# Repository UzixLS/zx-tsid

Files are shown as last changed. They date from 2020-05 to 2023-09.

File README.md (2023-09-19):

## ZX-TSid
MOS SID sound card for ZX Spectrum edge connector (ZX-BUS).

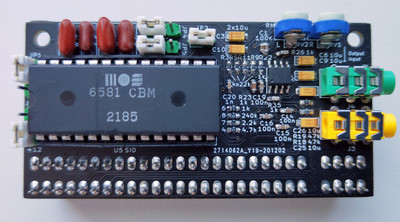
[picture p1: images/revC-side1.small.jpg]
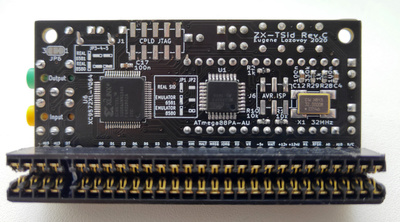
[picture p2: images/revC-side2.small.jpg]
 

PCB is compatible with SID 6581 and 8580, but also contains integrated SwinSID emulator.

SID accessible via #xxCF port, where xx - SID's register number.

You may connect your ZX Spectrum audio output to second 3.5mm jack and it will be mixed in sound card output signal.

NOTE: +12V/+9V voltage is strictly required for SID, your ZX Spectrum or clone must provide it on the edge connector.

### Changelog & current status
* Rev.A - initial release with SID, AY and Covox. [Errata](pcb/rev.A/ERRATA.txt).
* Rev.B - abandoned. Files kept for historical reason.
* Rev.C - removed AY and Covox. Added SwinSID emulator. PCB is vertical oriented now.
* Rev.D - improved signal-noise ratio. Fixed read from SID chip.

TODO:
* Check with 8580 SID chip;
* Further improve signal-noise ratio.

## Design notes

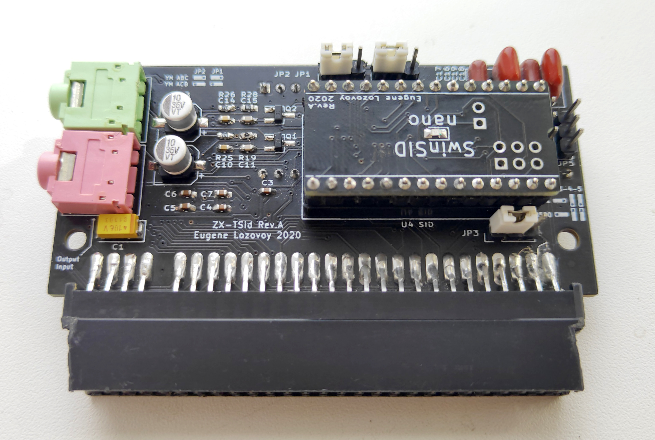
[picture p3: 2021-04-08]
images/revA-side1.jpg

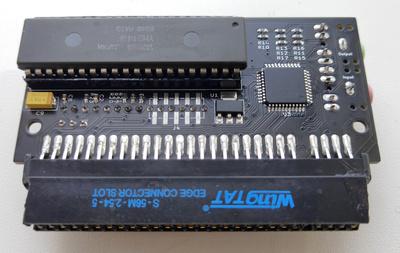
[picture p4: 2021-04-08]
images/revA-side2.small.jpg

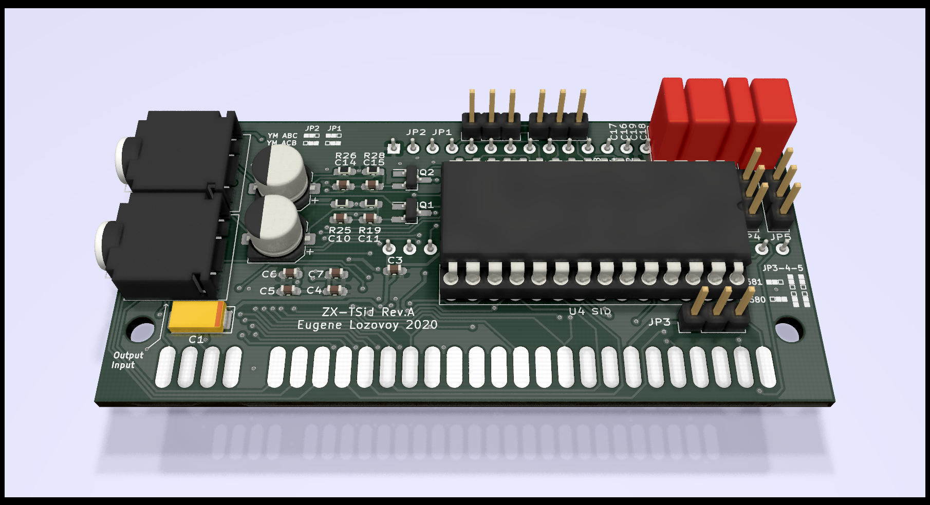
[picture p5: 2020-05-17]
out/pcb3d-top.rev.A.png

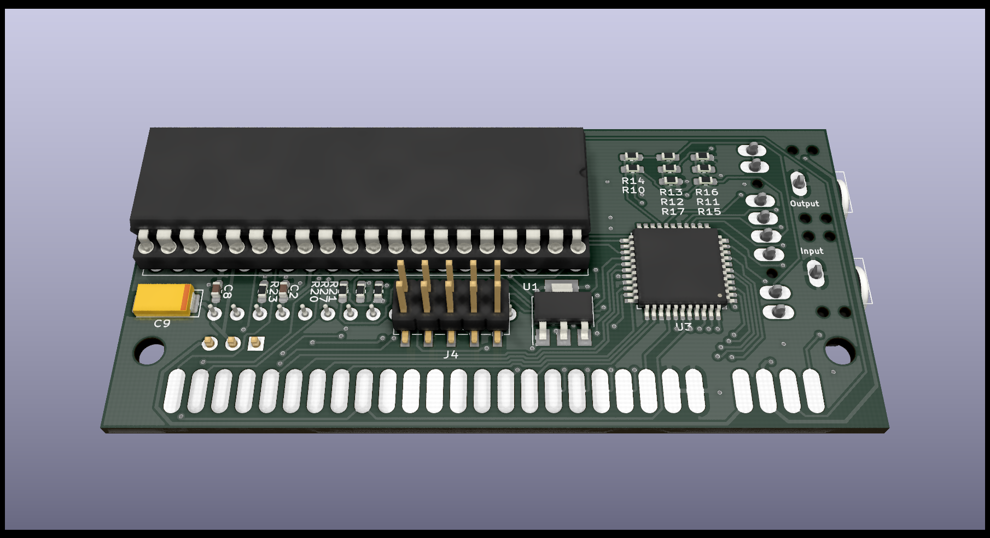
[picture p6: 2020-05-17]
out/pcb3d-bottom.rev.A.png

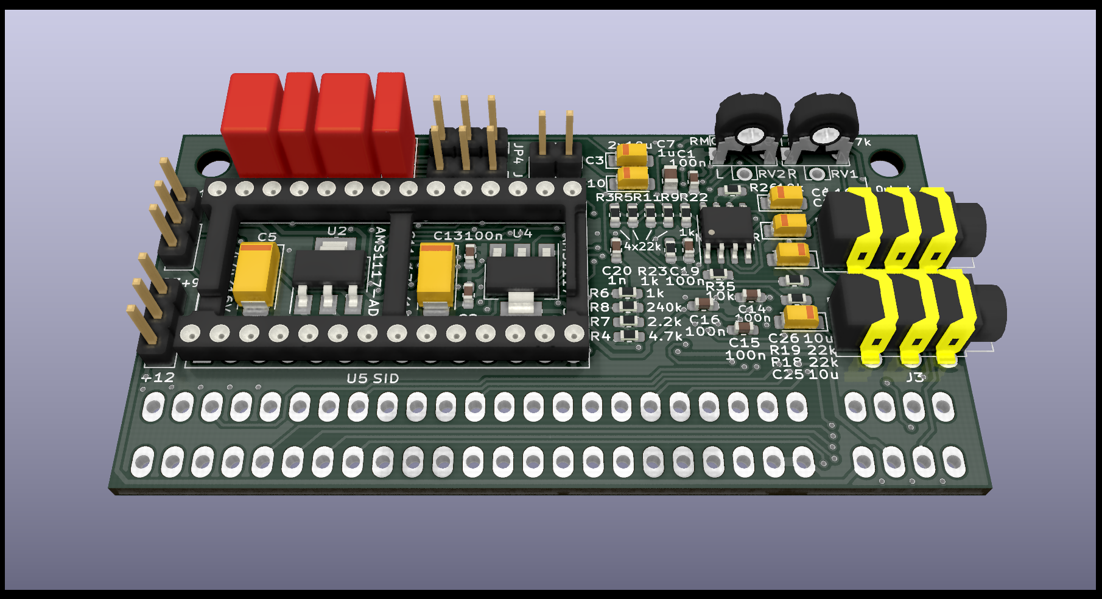
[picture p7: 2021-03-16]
out/pcb3d-bottom.rev.D.png

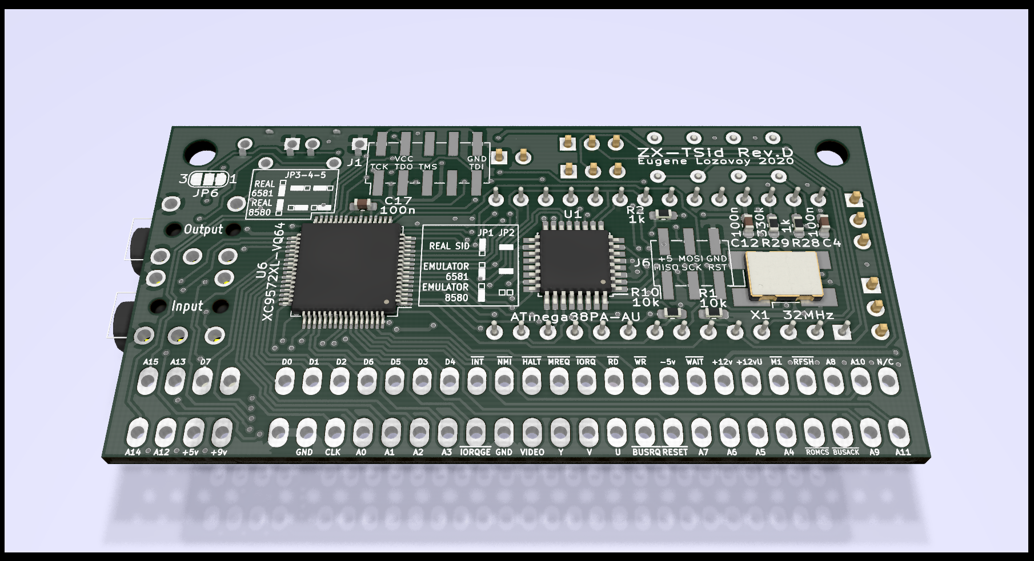
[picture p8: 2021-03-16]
out/pcb3d-top.rev.D.png

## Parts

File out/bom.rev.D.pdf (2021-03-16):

Designator | Package | Designation | Quantity
C11,C5 | CP_EIA-6032-28_Kemet-C_Pad2.25x2.35mm_HandSolder | 47u/16V | 2
C2,C19,C1,C4,C12,C17,C1 6,C15,C14,C13 | C_0603_1608Metric_Pad1.05x0.95mm_HandSolder | 100n | 10
C20 | C_0603_1608Metric_Pad1.05x0.95mm_HandSolder | 1n | 1
C22,C18 | C_Rect_L7.0mm_W4.5mm_P5.00mm | 470p | 2
C24,C21 | C_Rect_L7.0mm_W2.5mm_P5.00mm | 22n | 2
C3,C26,C25,C10,C6,C9 | CP_EIA-3216-18_Kemet-A_Pad1.58x1.35mm_HandSolder | 10u | 6
C7 | C_0805_2012Metric_Pad1.15x1.40mm_HandSolder | 1u | 1
H2,H1 | MountingHole_3.2mm_M3 | MountingHole | 2
J1 | PinHeader_2x05_P2.54mm_Vertical_SMD | Conn_02x05_Odd_Even | 1
J4,J3 | PJ-313 | PJ-313 | 2
J6 | PinHeader_2x03_P2.54mm_Vertical_SMD | Conn_02x03_Odd_Even | 1
JP1,JP5,JP4,JP3 | PinHeader_1x03_P2.54mm_Vertical | Jumper_3_Open | 4
JP2 | PinHeader_1x02_P2.54mm_Vertical | Jumper | 1
R10,R1,R35,R26 | R_0603_1608Metric_Pad1.05x0.95mm_HandSolder | 10k | 4
R11,R3,R9,R5,R19,R18 | R_0603_1608Metric_Pad1.05x0.95mm_HandSolder | 22k | 6
R12 | R_0603_1608Metric_Pad1.05x0.95mm_HandSolder | 240 | 1
R13,R6,R2,R23,R22,R28 | R_0603_1608Metric_Pad1.05x0.95mm_HandSolder | 1k | 6
R29 | R_0603_1608Metric_Pad1.05x0.95mm_HandSolder | 330k | 1
R4 | R_0603_1608Metric_Pad1.05x0.95mm_HandSolder | 4.7k | 1
R7 | R_0603_1608Metric_Pad1.05x0.95mm_HandSolder | 2.2k | 1
R8 | R_0603_1608Metric_Pad1.05x0.95mm_HandSolder | 240k | 1
RV2,RV1 | Potentiometer_Runtron_RM-063_Horizontal | RM063 47k | 2
U1 | TQFP-32_7x7mm_P0.8mm | ATmega88PA-AU | 1
U2 | SOT-223-3_TabPin2 | AMS1117-ADJ | 1
U3 | SOIC-8_3.9x4.9mm_P1.27mm | NE5532DR | 1
U4 | SOT-223-3_TabPin2 | AMS1117-3.3 | 1
U5 | DIP-28_W15.24mm_Socket | 8580 | 1
U6 | TQFP-64_10x10mm_P0.5mm | XC9572XL-VQ64 | 1
X1 | Oscillator_SMD_EuroQuartz_XO91-4Pin_7.0x5.0mm_HandSoldering | 32MHz | 1

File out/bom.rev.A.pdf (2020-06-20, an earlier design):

Designator | Package | Designation | Quantity
C10,C14 | C_0603_1608Metric_Pad1.05x0.95mm_HandSolder | 1n | 2
C11,C15 | C_0603_1608Metric_Pad1.05x0.95mm_HandSolder | 470p | 2
C12,C13 | CP_Elec_6.3x5.4 | 10u | 2
C18,C16 | C_Rect_L7.0mm_W4.5mm_P5.00mm | 470p | 2
C19,C17 | C_Rect_L7.0mm_W2.5mm_P5.00mm | 22n | 2
C8,C2,C7,C6,C5,C4,C3 | C_0603_1608Metric_Pad1.05x0.95mm_HandSolder | 100n | 7
C9,C1 | CP_EIA-6032-15_Kemet-U_Pad2.25x2.35mm_HandSolder | 100u/16V | 2
H2,H1 | MountingHole_3.2mm_M3 | MountingHole | 2
J1 | ZX_CONN | zx_edge | 1
J2,J3 | SWITCHCRAFT_35RAPC4BHN2 | PJ307 | 2
J4 | PinHeader_2x05_P2.54mm_Vertical_SMD | Conn_02x05_Odd_Even | 1
JP5,JP4,JP3,JP2,JP1 | PinHeader_1x03_P2.54mm_Vertical | Jumper_3_Open | 5
Q1,Q2 | SOT-23_Handsoldering | BC847 | 2
R17,R16,R15,R10,R13,R12,R11,R 14,R6,R2,R27,R21,R20 | R_0603_1608Metric_Pad1.05x0.95mm_HandSolder | 10k | 13
R19,R9,R8,R7,R1,R28,R22 | R_0603_1608Metric_Pad1.05x0.95mm_HandSolder | 1k | 7
R23 | R_0603_1608Metric_Pad1.05x0.95mm_HandSolder | 100k | 1
R24,R18 | R_0603_1608Metric_Pad1.05x0.95mm_HandSolder | 22k | 2
R26,R25 | R_0603_1608Metric_Pad1.05x0.95mm_HandSolder | 47k | 2
R4 | R_0603_1608Metric_Pad1.05x0.95mm_HandSolder | 4.7k | 1
R5,R3 | R_0603_1608Metric_Pad1.05x0.95mm_HandSolder | 2k | 2
U1 | SOT-223-3_TabPin2 | AMS1117-3.3 | 1
U2 | DIP-40_W15.24mm_Socket | YM2149 | 1
U3 | QFP80P1200X1200X120-44N | EPM3064ATC44-10N | 1
U4 | DIP-28_W15.24mm_Socket | 8580 | 1

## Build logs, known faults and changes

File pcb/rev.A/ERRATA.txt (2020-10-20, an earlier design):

Quiet sound output from nanoSwinSID.

Incorrect A8 and A10 signal connections on ZXBUS connector. A8 should be connected to pin B26 and A10 to B27 to get SID working.

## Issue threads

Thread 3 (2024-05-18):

ask for add ZXi ports

LMN128, 2024-05-18:
Could you add access by ZXi ports too, please. Some SW use it. It comes better compatibility. Thanks a lot.
Info here: https://sinclair.wiki.zxnet.co.uk/wiki/ZXI_standard

tech spec:
```
ZX Spectrum SID on ZXi ports

h6C3B – select SID Control Register
h6D3B – read/write selected SID Control Register

Registers:
h00 to h1C - original SID registers

h1F - optional - select SID parameters
	bit 0 - SID type:  0-6581; 1-8580
	bit 1 - Frequency: 0-PAL;  1-NTSC (985248Hz for PAL C64, 1022730Hz for NTSC C64)
	bits 2-7 - always 0;
	note eLeMeNt ZX and MB03+ use FPGA implementation of SID that can switch type with related filters.

h20 - optional - select more SIDs (up to 256 SIDs) - useful for more than one SID
	       - in case of only one SID, is not needed to use it.

```

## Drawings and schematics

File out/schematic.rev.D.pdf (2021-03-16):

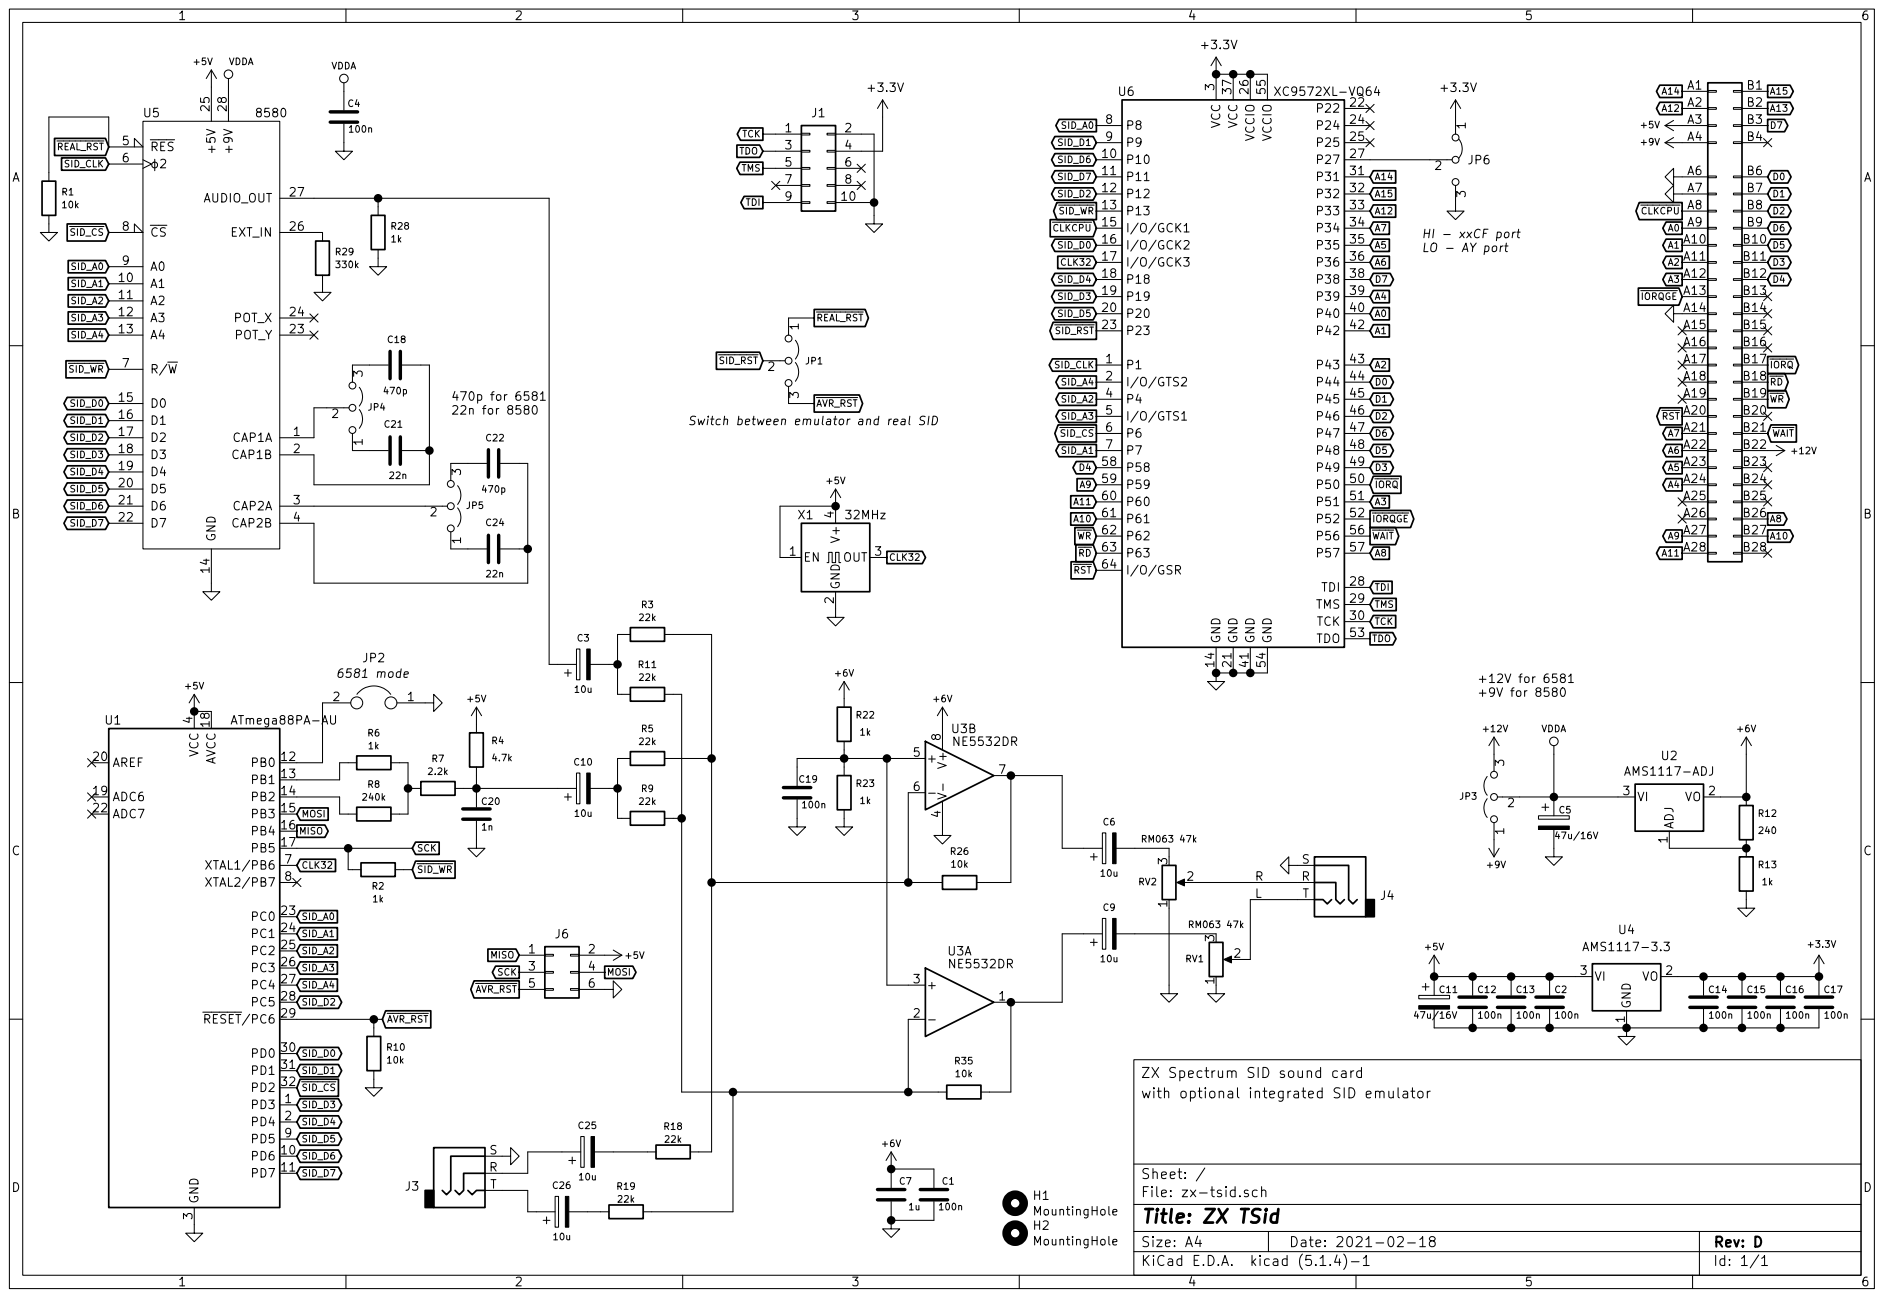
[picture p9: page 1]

LO - AY port +12V for 6581 +9V for 8580

JP1 Switch between emulator and real SID

ZX Spectrum SID sound card
File: zx-tsid.sch Sheet: / with optional integrated SID emulator

Id: 1/1 Title: ZX TSid

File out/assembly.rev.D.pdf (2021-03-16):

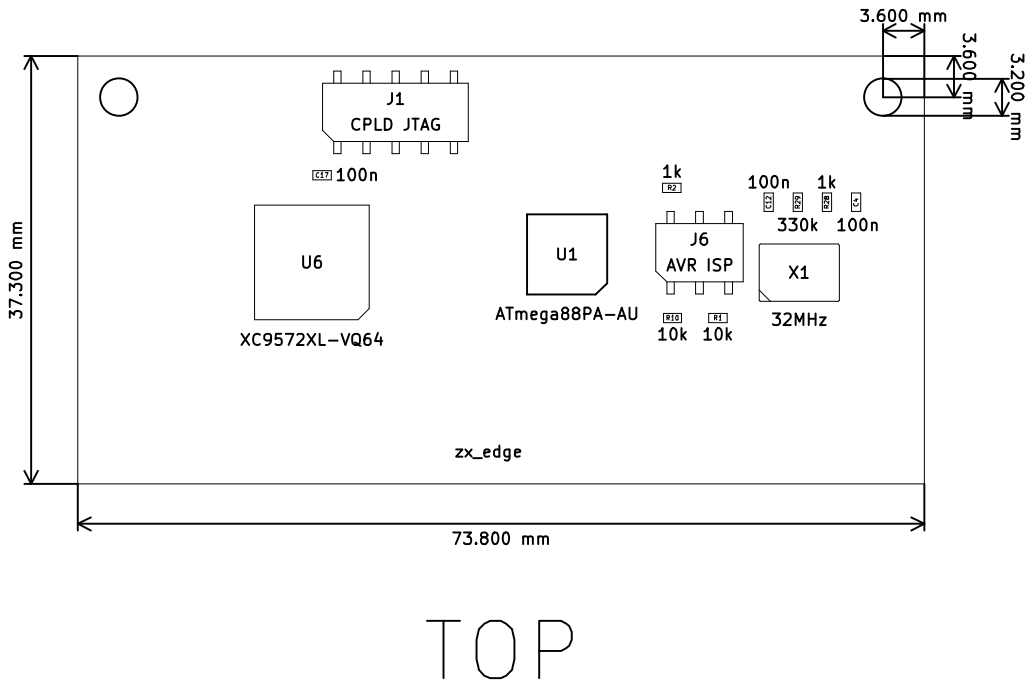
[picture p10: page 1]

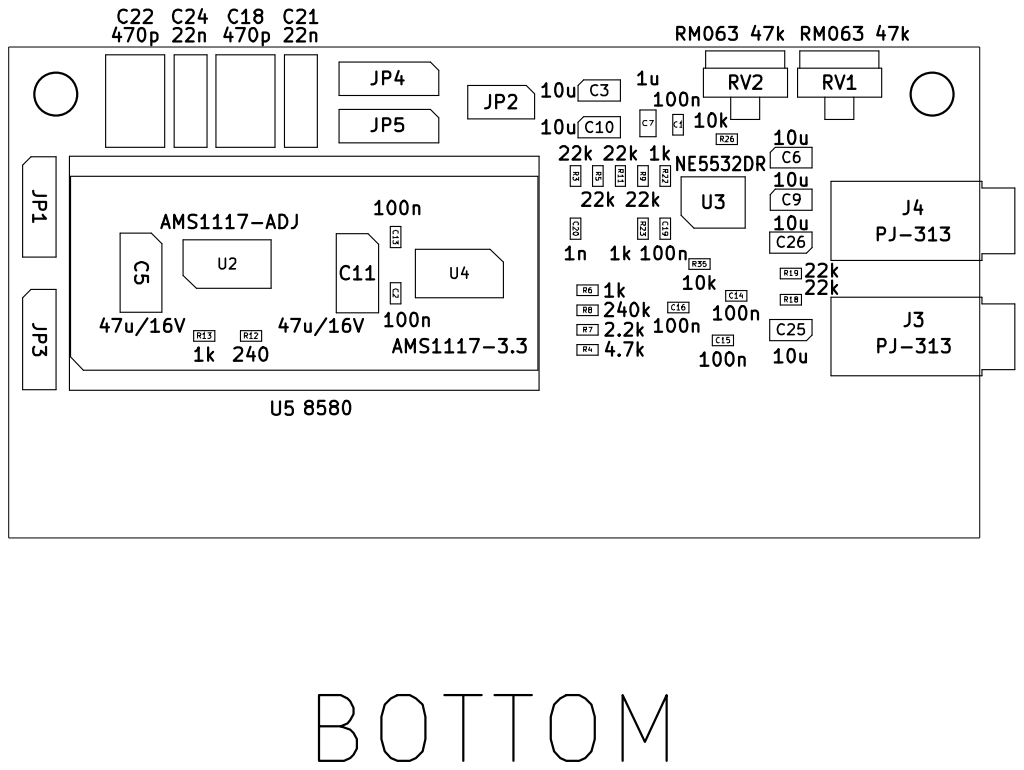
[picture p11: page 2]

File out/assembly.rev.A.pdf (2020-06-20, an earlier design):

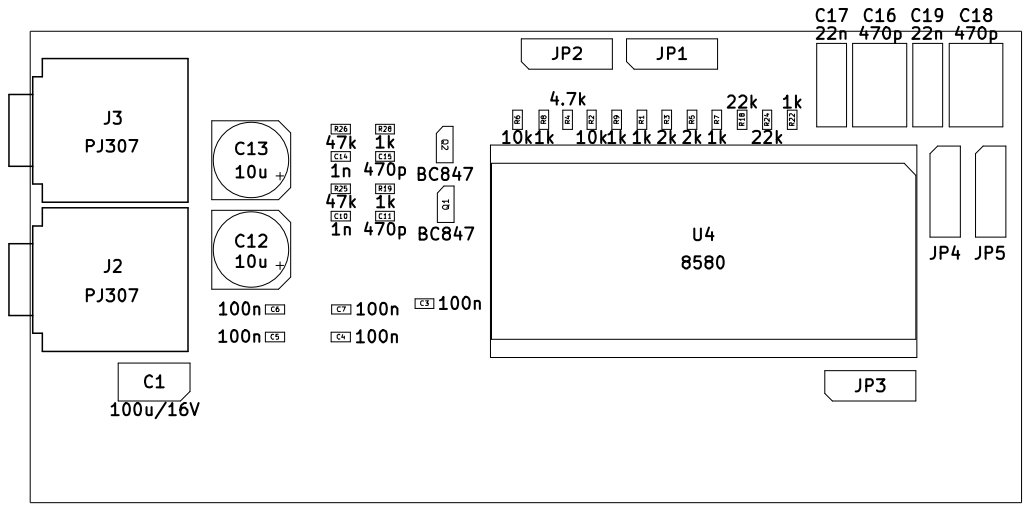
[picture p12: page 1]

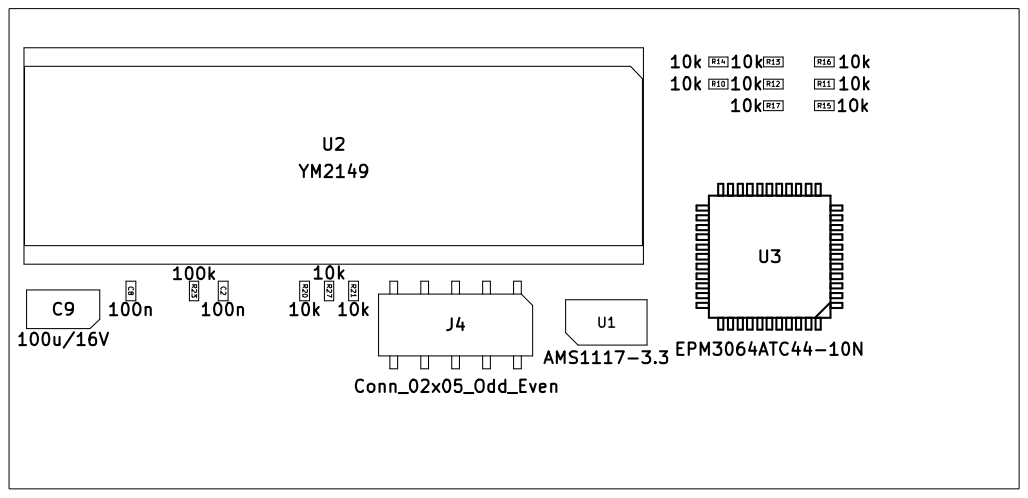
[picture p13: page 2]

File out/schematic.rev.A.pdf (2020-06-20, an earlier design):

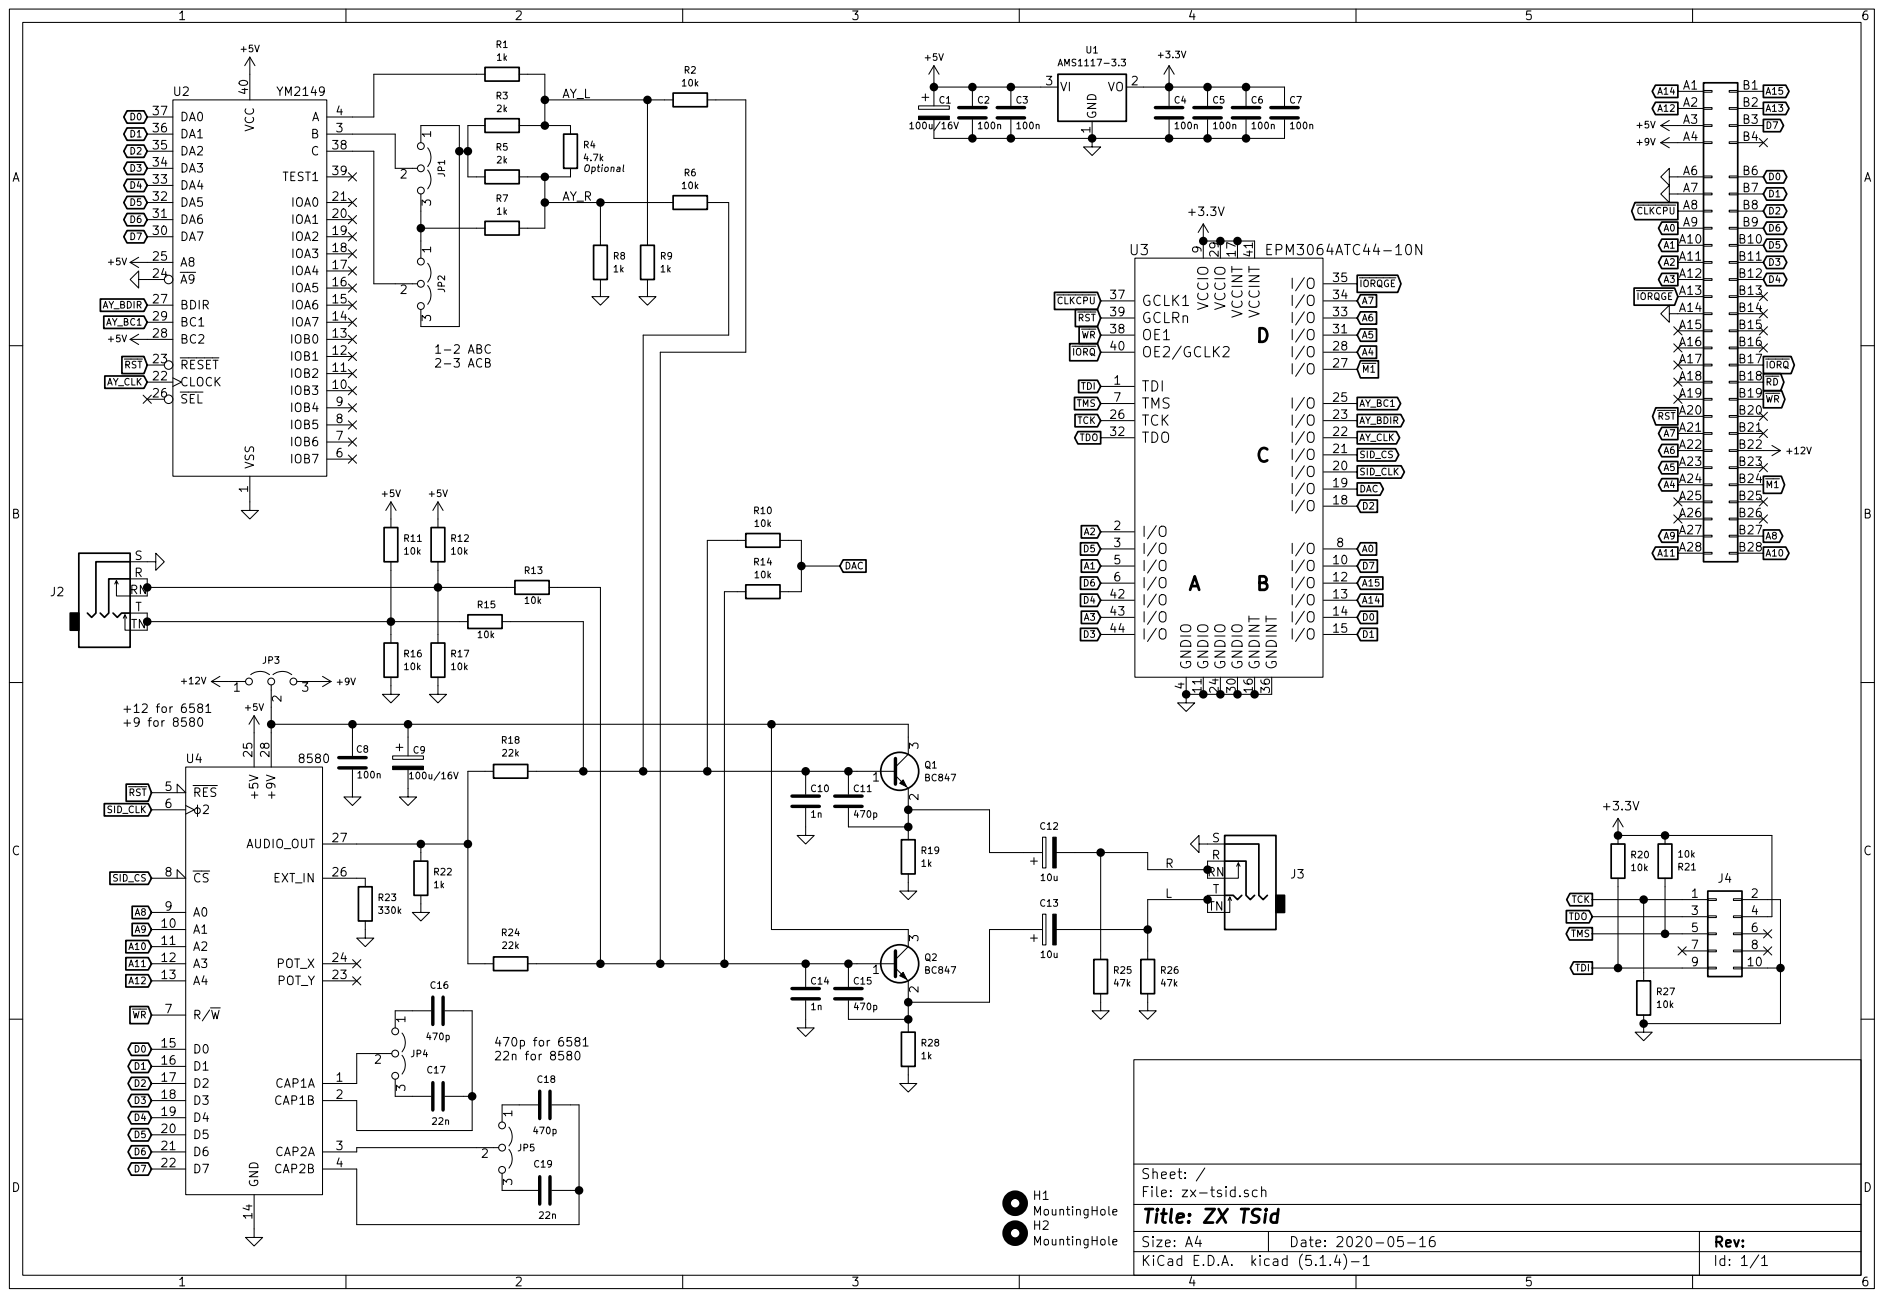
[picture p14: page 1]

File: zx-tsid.sch Sheet: /
Id: 1/1 Title: ZX TSid

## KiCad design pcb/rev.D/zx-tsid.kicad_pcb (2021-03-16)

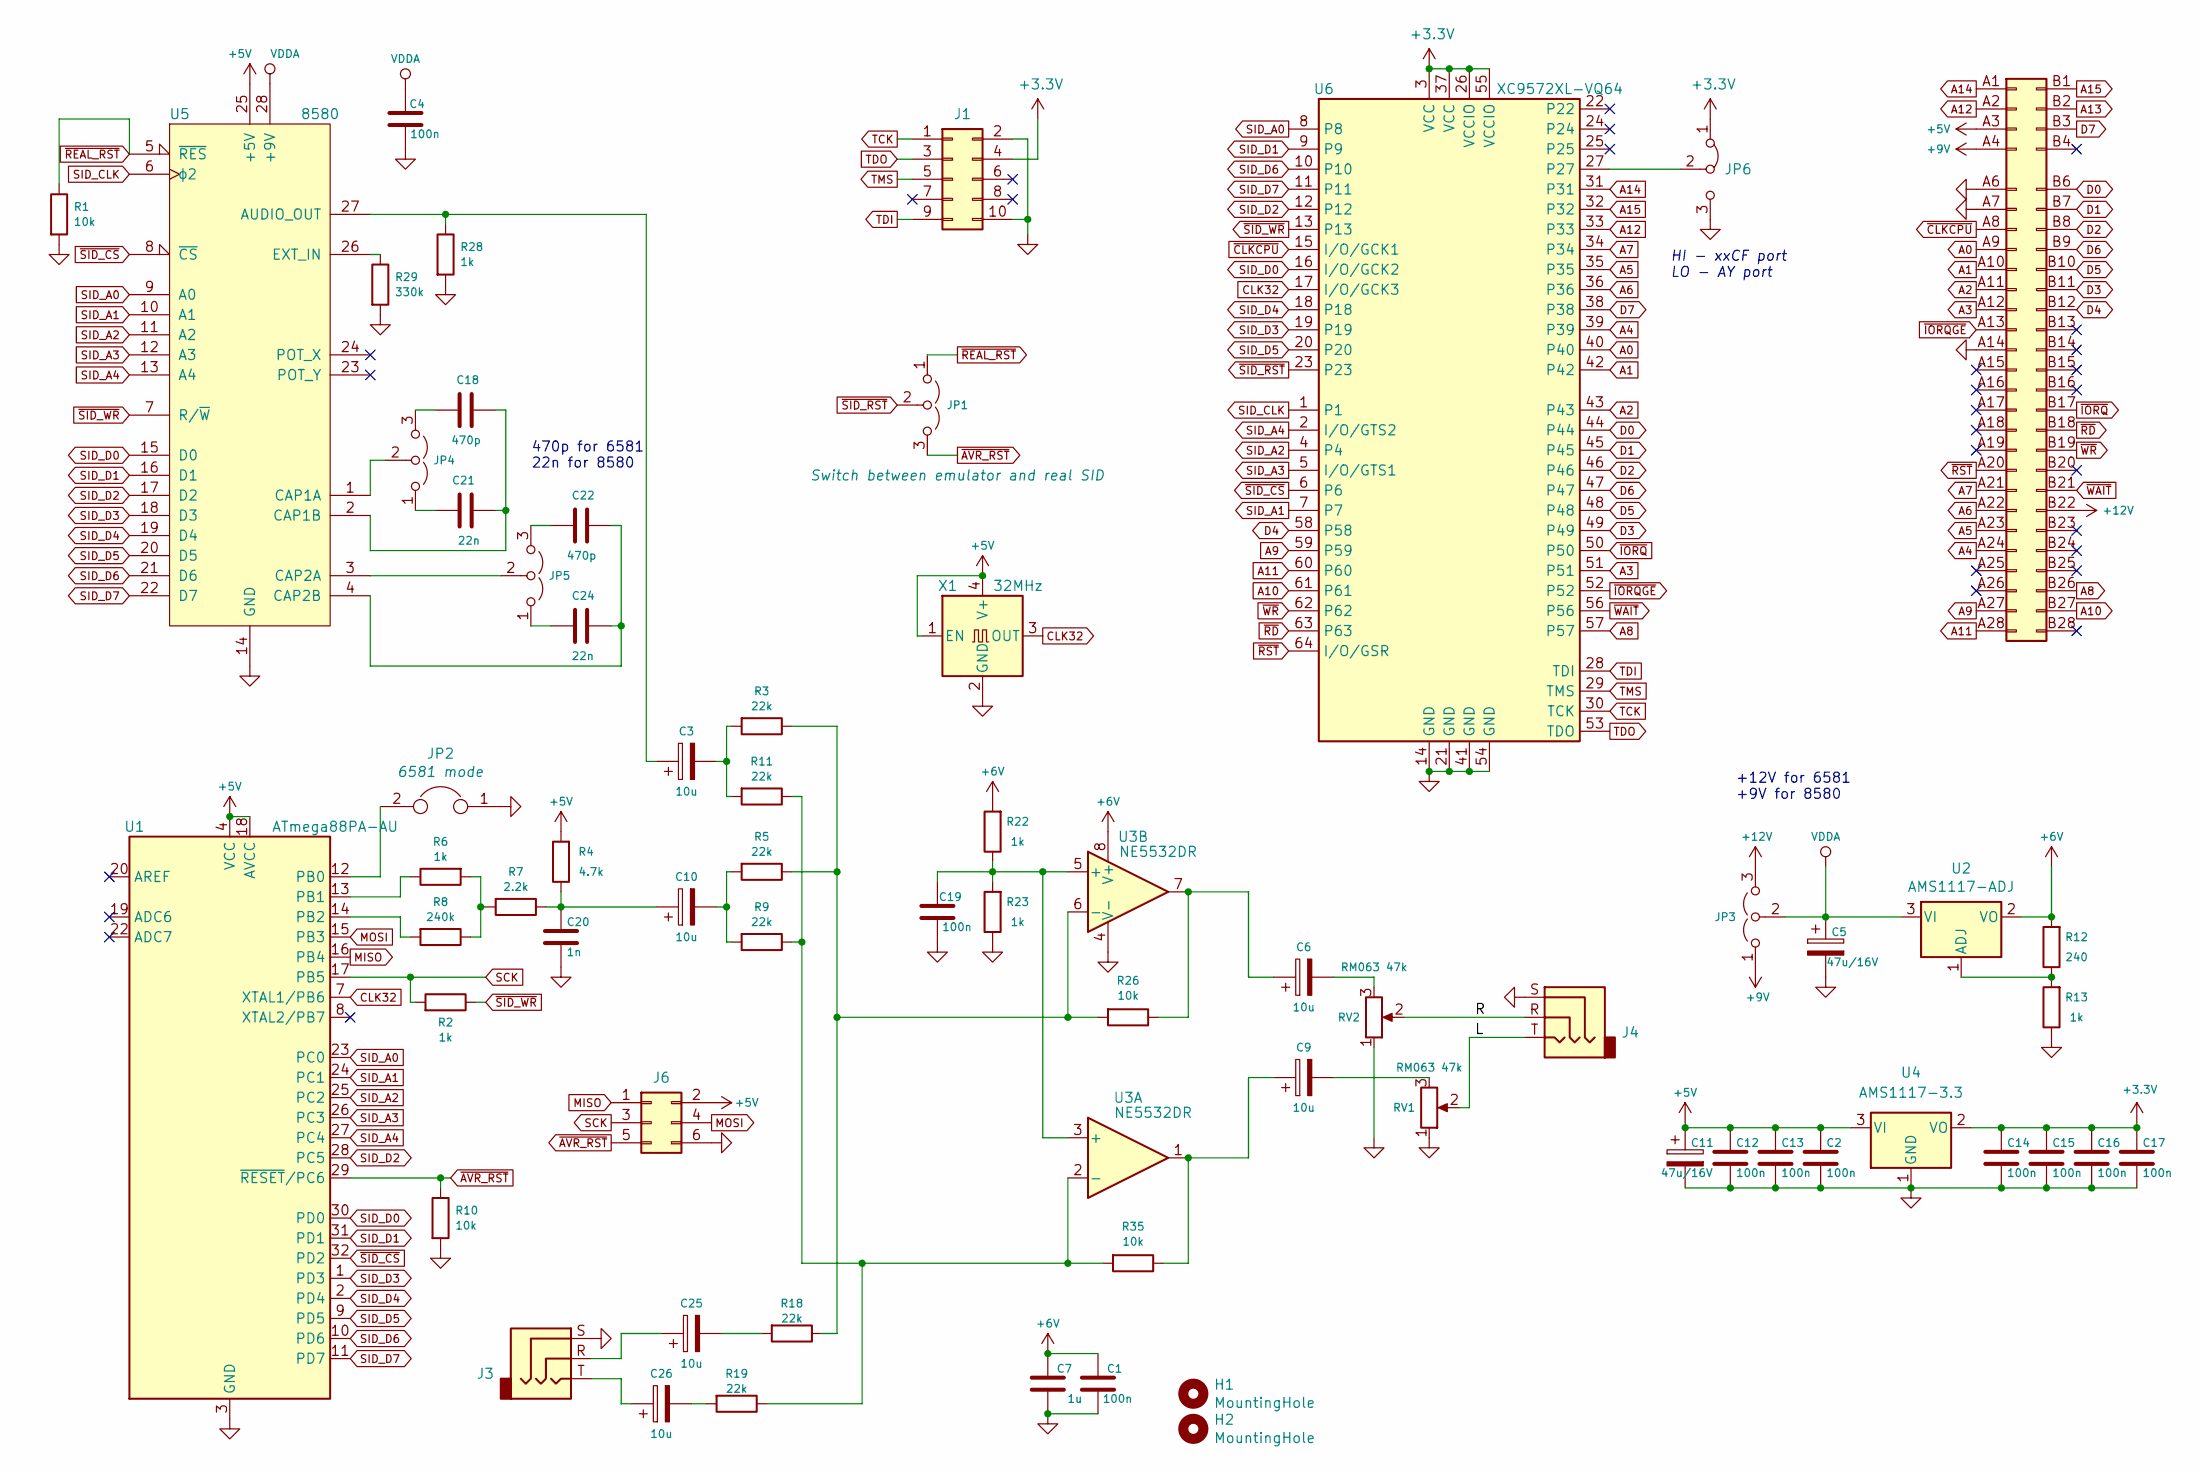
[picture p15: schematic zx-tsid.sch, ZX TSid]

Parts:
C1, C2, C4, C12, C13, C14, C15, C16, C17, C19: 100n; C_0603_1608Metric_Pad1.05x0.95mm_HandSolder
C3, C6, C9, C10, C25, C26: 10u; CP_EIA-3216-18_Kemet-A_Pad1.58x1.35mm_HandSolder
C5, C11: 47u/16V; CP_EIA-6032-28_Kemet-C_Pad2.25x2.35mm_HandSolder
C7: 1u; C_0805_2012Metric_Pad1.15x1.40mm_HandSolder
C18, C22: 470p; C_Rect_L7.0mm_W4.5mm_P5.00mm
C20: 1n; C_0603_1608Metric_Pad1.05x0.95mm_HandSolder
C21, C24: 22n; C_Rect_L7.0mm_W2.5mm_P5.00mm
H1, H2: MountingHole; MountingHole_3.2mm_M3
J1: Conn_02x05_Odd_Even; PinHeader_2x05_P2.54mm_Vertical_SMD
J2: zx_edge; Spectrum_Edge_Connector
J3, J4: PJ-313
J6: Conn_02x03_Odd_Even; PinHeader_2x03_P2.54mm_Vertical_SMD
JP1, JP3, JP4, JP5: Jumper_3_Open; PinHeader_1x03_P2.54mm_Vertical
JP2: Jumper; PinHeader_1x02_P2.54mm_Vertical
JP6: Jumper_3_Bridged12; SolderJumper-3_P1.3mm_Bridged12_RoundedPad1.0x1.5mm_NumberL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
R1, R10, R26, R35: 10k; R_0603_1608Metric_Pad1.05x0.95mm_HandSolder
R2, R6, R13, R22, R23, R28: 1k; R_0603_1608Metric_Pad1.05x0.95mm_HandSolder
R3, R5, R9, R11, R18, R19: 22k; R_0603_1608Metric_Pad1.05x0.95mm_HandSolder
R4: 4.7k; R_0603_1608Metric_Pad1.05x0.95mm_HandSolder
R7: 2.2k; R_0603_1608Metric_Pad1.05x0.95mm_HandSolder
R8: 240k; R_0603_1608Metric_Pad1.05x0.95mm_HandSolder
R12: 240; R_0603_1608Metric_Pad1.05x0.95mm_HandSolder
R29: 330k; R_0603_1608Metric_Pad1.05x0.95mm_HandSolder
RV1, RV2: RM063 47k; Potentiometer_Runtron_RM-063_Horizontal
U1: ATmega88PA-AU; TQFP-32_7x7mm_P0.8mm
U2: AMS1117-ADJ; SOT-223-3_TabPin2
U3: NE5532DR; SOIC-8_3.9x4.9mm_P1.27mm
U4: AMS1117-3.3; SOT-223-3_TabPin2
U5: 8580; DIP-28_W15.24mm_Socket
U6: XC9572XL-VQ64; TQFP-64_10x10mm_P0.5mm
X1: 32MHz; Oscillator_SMD_EuroQuartz_XO91-4Pin_7.0x5.0mm_HandSoldering

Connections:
+3V3: C14.1, C15.1, C16.1, C17.1, J1.4, JP6.1 (A), U4.2 (VO), U6.3 (VCC), U6.26 (VCCIO), U6.37 (VCC), U6.55 (VCCIO)
+5V: C2.1, C11.1, C12.1, C13.1, J2.A3 (Pin_a3), J6.2, R4.2, U1.4 (VCC), U1.6 (VCC), U1.18 (AVCC), U4.3 (VI), U5.25 (+5V), X1.1 (EN), X1.4 (V+)
+6V: C1.2, C7.2, R12.2, R22.2, U2.2 (VO), U3.8 (V+)
+9V: J2.A4 (Pin_a4), JP3.1 (A)
+12V: J2.B22 (Pin_b22), JP3.3 (B)
/L: J4.T, RV1.2
/R: J4.R, RV2.2
A0: J2.A9 (Pin_a9), U6.40
A1: J2.A10 (Pin_a10), U6.42
A2: J2.A11 (Pin_a11), U6.43
A3: J2.A12 (Pin_a12), U6.51
A4: J2.A24 (Pin_a24), U6.39
A5: J2.A23 (Pin_a23), U6.35
A6: J2.A22 (Pin_a22), U6.36
A7: J2.A21 (Pin_a21), U6.34
A8: J2.B26 (Pin_b26), U6.57
A9: J2.A27 (Pin_a27), U6.59
A10: J2.B27 (Pin_b27), U6.61
A11: J2.A28 (Pin_a28), U6.60
A12: J2.A2 (Pin_a2), U6.33
A14: J2.A1 (Pin_a1), U6.31
A15: J2.B1 (Pin_b1), U6.32
CLK32: U1.7 (XTAL1/PB6), U6.17 (I/O/GCK3), X1.3 (OUT)
D0: J2.B6 (Pin_b6), U6.44
D1: J2.B7 (Pin_b7), U6.45
D2: J2.B8 (Pin_b8), U6.46
D3: J2.B11 (Pin_b11), U6.49
D4: J2.B12 (Pin_b12), U6.58
D5: J2.B10 (Pin_b10), U6.48
D6: J2.B9 (Pin_b9), U6.47
D7: J2.B3 (Pin_b3), U6.38
GND: C1.1, C2.2, C4.1, C5.2, C7.1, C11.2, C12.2, C13.2, C14.2, C15.2, C16.2, C17.2, C19.1, C20.2, J1.2, J1.10, J2.A6 (Pin_a6), J2.A7 (Pin_a7), J2.A14 (Pin_a14), J3.S, J4.S, J6.6, JP2.1, JP6.3 (B), R1.2, R10.2, R13.1, R23.1, R28.2, R29.2, RV1.1, RV2.1, U1.3 (GND), U1.5 (GND), U1.21 (GND), U3.4 (V-), U4.1 (GND), U5.14 (GND), U6.14 (GND), U6.21 (GND), U6.41 (GND), U6.54 (GND), X1.2 (GND)
MISO: J6.1, U1.16 (PB4)
MOSI: J6.4, U1.15 (PB3)
unnamed: C3.1, R28.1, U5.27 (AUDIO_OUT)
unnamed: C3.2, R3.2, R11.2
unnamed: C6.1, R26.1, U3.7
unnamed: C6.2, RV2.3
unnamed: C9.1, R35.1, U3.1
unnamed: C9.2, RV1.3
unnamed: C10.1, C20.1, R4.1, R7.1
unnamed: C10.2, R5.2, R9.2
unnamed: C18.1, C21.2, U5.2 (CAP1B)
unnamed: C18.2, JP4.3 (B)
unnamed: C19.2, R22.1, R23.2, U3.3 (+), U3.5 (+)
unnamed: C21.1, JP4.1 (A)
unnamed: C22.1, C24.1, U5.4 (CAP2B)
unnamed: C22.2, JP5.3 (B)
unnamed: C24.2, JP5.1 (A)
unnamed: C25.1, J3.R
unnamed: C25.2, R18.2
unnamed: C26.1, J3.T
unnamed: C26.2, R19.2
unnamed: JP2.2, U1.12 (PB0)
unnamed: JP4.2 (C), U5.1 (CAP1A)
unnamed: JP5.2 (C), U5.3 (CAP2A)
unnamed: JP6.2 (C), U6.27
unnamed: R6.1, U1.13 (PB1)
unnamed: R6.2, R7.2, R8.1
unnamed: R8.2, U1.14 (PB2)
unnamed: R9.1, R11.1, R19.1, R35.2, U3.2 (-)
unnamed: R12.1, R13.2, U2.1 (ADJ)
unnamed: R3.1, R5.1, R18.1, R26.2, U3.6 (-)
unnamed: R29.1, U5.26 (EXT_IN)
SCK: J6.3, R2.2, U1.17 (PB5)
SID_A0: U1.23 (PC0), U5.9 (A0), U6.8
SID_A1: U1.24 (PC1), U5.10 (A1), U6.7
SID_A2: U1.25 (PC2), U5.11 (A2), U6.4
SID_A3: U1.26 (PC3), U5.12 (A3), U6.5 (I/O/GTS1)
SID_A4: U1.27 (PC4), U5.13 (A4), U6.2 (I/O/GTS2)
SID_CLK: U5.6 (ϕ2), U6.1
SID_D0: U1.30 (PD0), U5.15 (D0), U6.16 (I/O/GCK2)
SID_D1: U1.31 (PD1), U5.16 (D1), U6.9
SID_D2: U1.28 (PC5), U5.17 (D2), U6.12
SID_D3: U1.1 (PD3), U5.18 (D3), U6.19
SID_D4: U1.2 (PD4), U5.19 (D4), U6.18
SID_D5: U1.9 (PD5), U5.20 (D5), U6.20
SID_D6: U1.10 (PD6), U5.21 (D6), U6.10
SID_D7: U1.11 (PD7), U5.22 (D7), U6.11
TCK: J1.1, U6.30 (TCK)
TDI: J1.9, U6.28 (TDI)
TDO: J1.3, U6.53 (TDO)
TMS: J1.5, U6.29 (TMS)
VDDA: C4.2, C5.1, JP3.2 (C), U2.3 (VI), U5.28 (+9V)
~AVR_RST: J6.5, JP1.3 (B), R10.1, U1.29 (~RESET~/PC6)
~CLKCPU: J2.A8 (Pin_a8), U6.15 (I/O/GCK1)
~IORQ: J2.B17 (Pin_b17), U6.50
~IORQGE: J2.A13 (Pin_a13), U6.52
~RD: J2.B18 (Pin_b18), U6.63
~REAL_RST: JP1.1 (A), R1.1, U5.5 (~RES)
~RST: J2.A20 (Pin_a20), U6.64 (I/O/GSR)
~SID_CS: U1.32 (PD2), U5.8 (~CS), U6.6
~SID_RST: JP1.2 (C), U6.23
~SID_WR: R2.1, U5.7 (R/~W), U6.13
~WAIT: J2.B21 (Pin_b21), U6.56
~WR: J2.B19 (Pin_b19), U6.62

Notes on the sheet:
470p for 6581 22n for 8580
HI - xxCF port LO - AY port
+12V for 6581 +9V for 8580

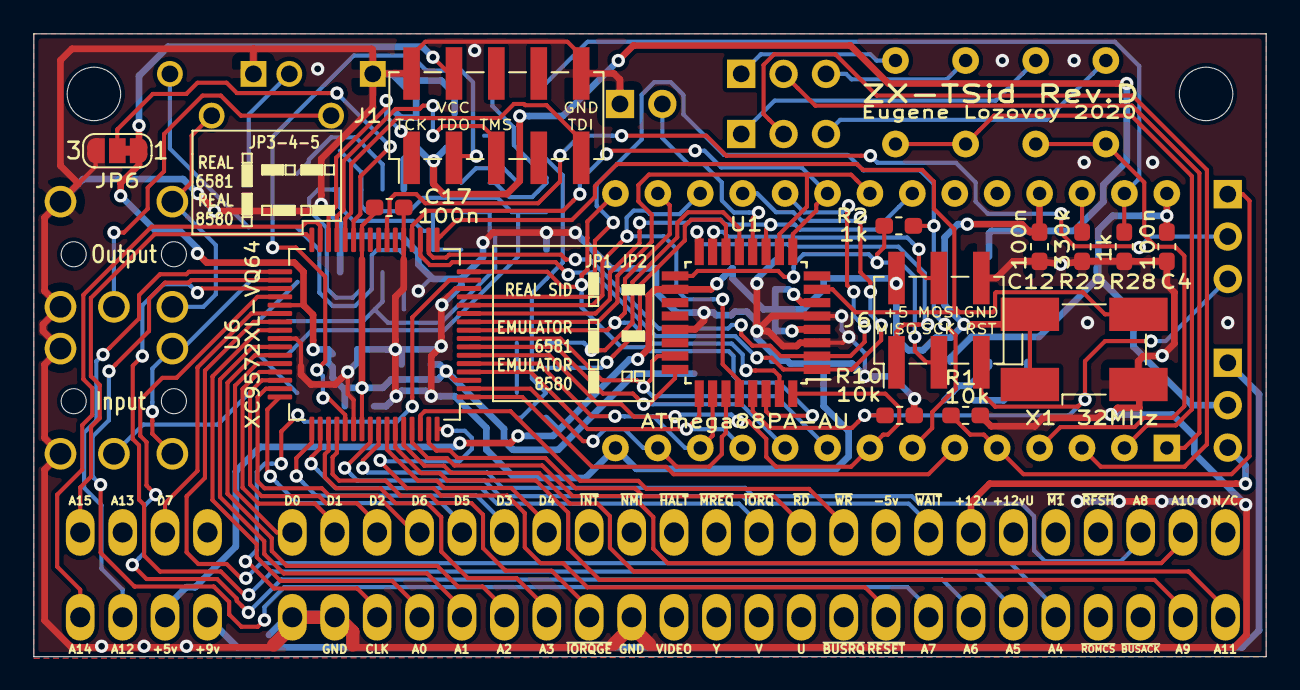
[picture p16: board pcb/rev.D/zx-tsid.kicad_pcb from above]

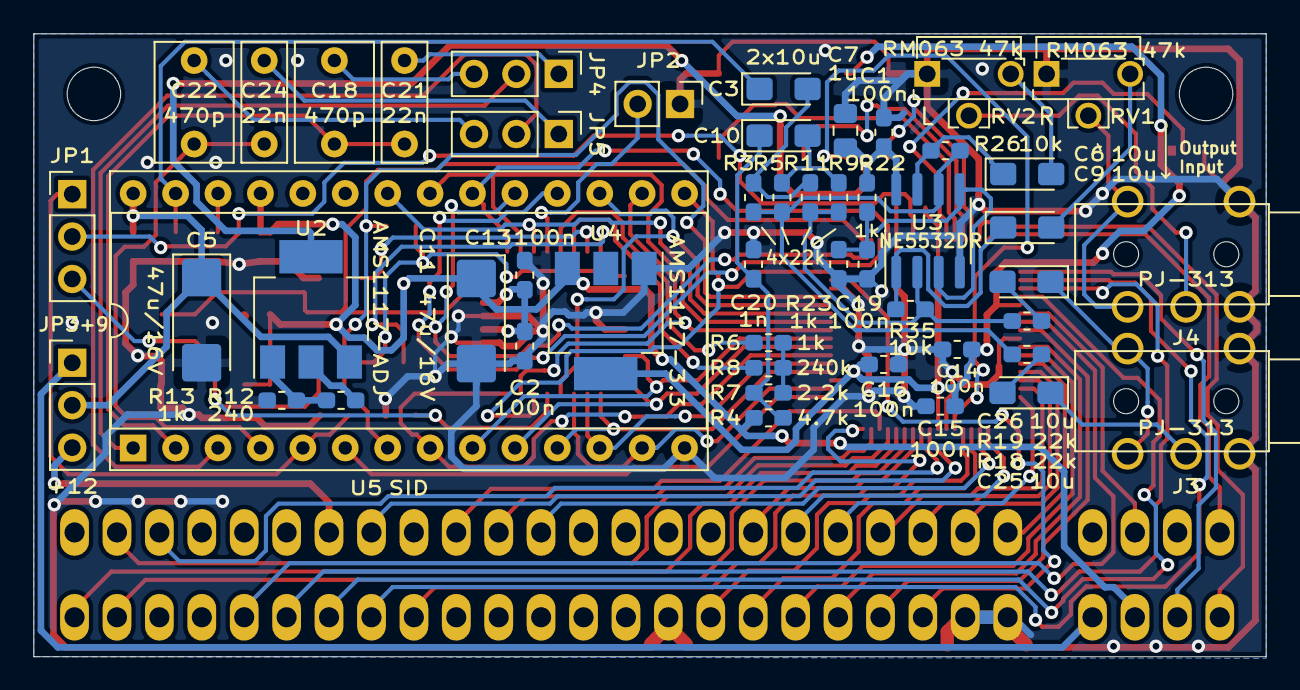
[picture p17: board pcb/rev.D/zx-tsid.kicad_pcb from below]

Board: 2 copper layers, 73.8 x 37.3 mm, 67 parts (52 on the bottom side), 96 nets.

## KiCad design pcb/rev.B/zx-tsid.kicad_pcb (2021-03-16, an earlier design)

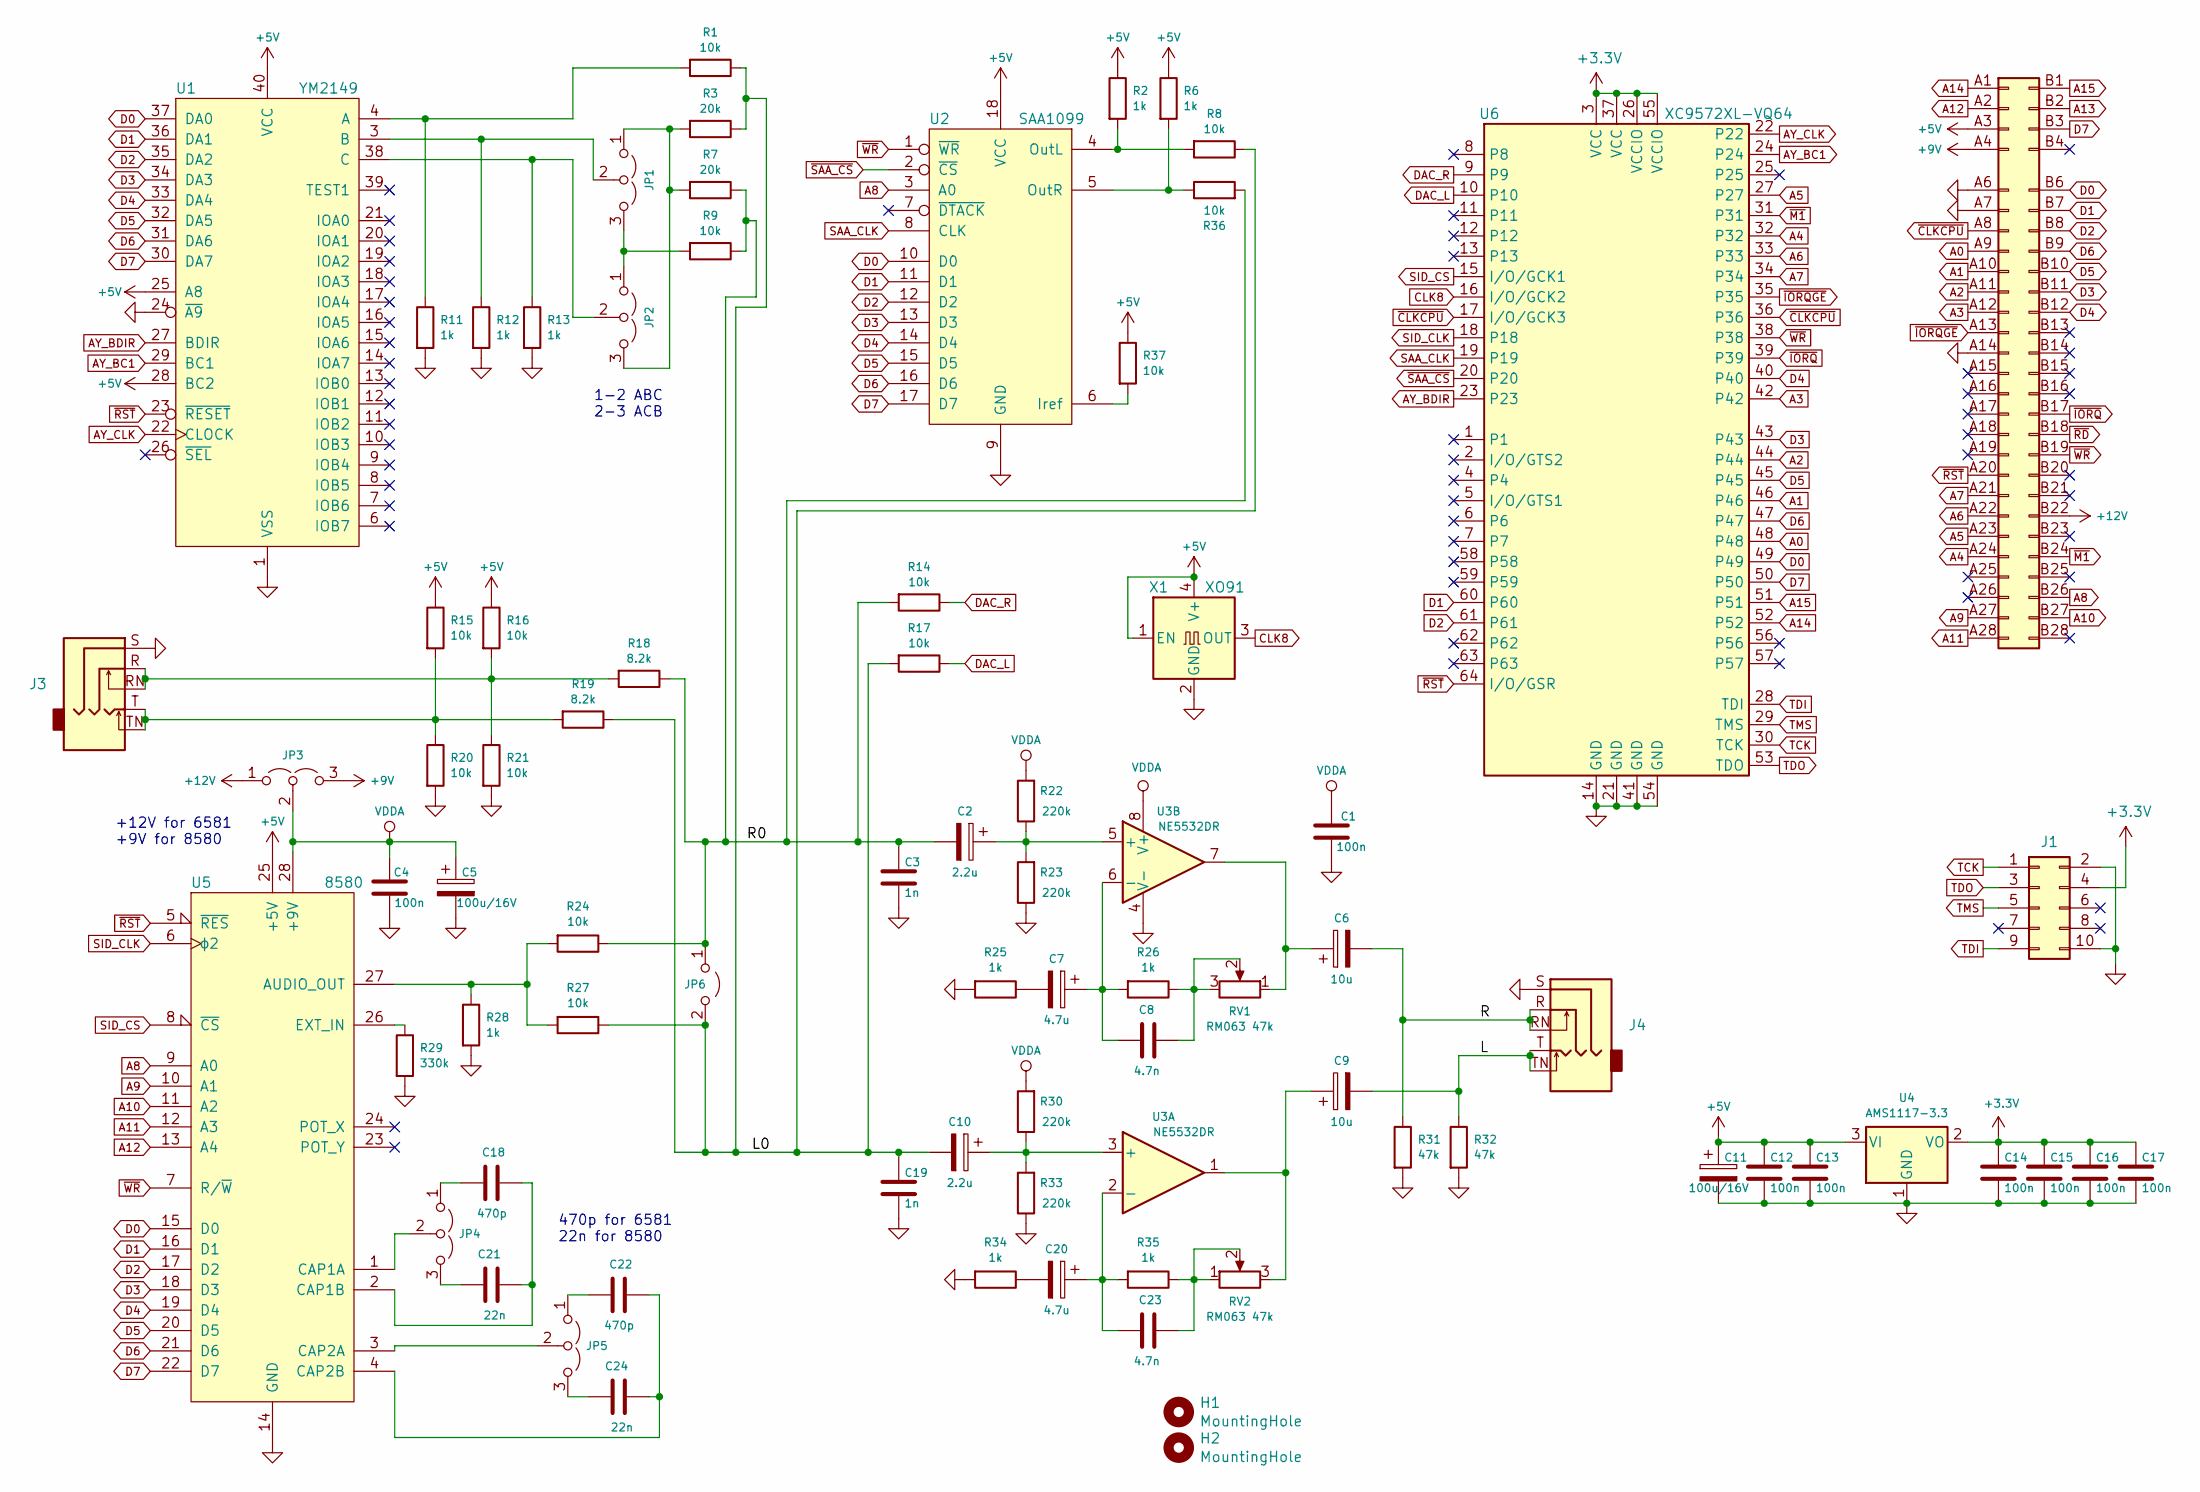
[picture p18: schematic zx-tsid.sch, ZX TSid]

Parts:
C1, C4, C12, C13, C14, C15, C16, C17: 100n; C_0603_1608Metric_Pad1.05x0.95mm_HandSolder
C2, C10: 2.2u; CP_EIA-3216-18_Kemet-A_Pad1.58x1.35mm_HandSolder
C3, C19: 1n; C_0603_1608Metric_Pad1.05x0.95mm_HandSolder
C5, C11: 100u/16V; CP_EIA-6032-28_Kemet-C_Pad2.25x2.35mm_HandSolder
C6, C9: 10u; CP_EIA-3216-18_Kemet-A_Pad1.58x1.35mm_HandSolder
C7, C20: 4.7u; CP_EIA-3216-18_Kemet-A_Pad1.58x1.35mm_HandSolder
C8, C23: 4.7n; C_0603_1608Metric_Pad1.05x0.95mm_HandSolder
C18, C22: 470p; C_Rect_L7.0mm_W4.5mm_P5.00mm
C21, C24: 22n; C_Rect_L7.0mm_W2.5mm_P5.00mm
H1, H2: MountingHole; MountingHole_3.2mm_M3
J1: Conn_02x05_Odd_Even; PinHeader_2x05_P2.54mm_Vertical_SMD
J2: zx_edge; ZX_CONN
J3, J4: PJ307
JP1, JP2, JP3, JP4, JP5: Jumper_3_Open; PinHeader_1x03_P2.54mm_Vertical
JP6: Jumper_2_Open; PinHeader_1x02_P2.54mm_Vertical
R1, R8, R9, R14, R15, R16, R17, R20, R21, R24, R27, R36, R37: 10k; R_0603_1608Metric_Pad1.05x0.95mm_HandSolder
R2, R6, R11, R12, R13, R25, R26, R28, R34, R35: 1k; R_0603_1608Metric_Pad1.05x0.95mm_HandSolder
R3, R7: 20k; R_0603_1608Metric_Pad1.05x0.95mm_HandSolder
R18, R19: 8.2k; R_0603_1608Metric_Pad1.05x0.95mm_HandSolder
R22, R23, R30, R33: 220k; R_0603_1608Metric_Pad1.05x0.95mm_HandSolder
R29: 330k; R_0603_1608Metric_Pad1.05x0.95mm_HandSolder
R31, R32: 47k; R_0603_1608Metric_Pad1.05x0.95mm_HandSolder
RV1, RV2: RM063 47k; Potentiometer_Runtron_RM-063_Horizontal
U1: YM2149; DIP-40_W15.24mm_Socket
U2: SAA1099; DIP-18_W7.62mm_Socket
U3: NE5532DR; SOIC-8_3.9x4.9mm_P1.27mm
U4: AMS1117-3.3; SOT-223-3_TabPin2
U5: 8580; DIP-28_W15.24mm_Socket
U6: XC9572XL-VQ64; TQFP-64_10x10mm_P0.5mm
X1: XO91; Oscillator_SMD_EuroQuartz_XO91-4Pin_7.0x5.0mm

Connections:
+3V3: C14.1, C15.1, C16.1, C17.1, J1.4, U4.2 (VO), U6.3 (VCC), U6.26 (VCCIO), U6.37 (VCC), U6.55 (VCCIO)
+5V: C11.1, C12.1, C13.1, J2.A3 (Pin_a3), R2.1, R6.1, R15.1, R16.1, R37.1, U1.25 (A8), U1.28 (BC2), U1.40 (VCC), U2.18 (VCC), U4.3 (VI), U5.25 (+5V), X1.1 (EN), X1.4 (V+)
+9V: J2.A4 (Pin_a4), JP3.3 (B)
+12V: J2.B22 (Pin_b22), JP3.1 (A)
/L: C9.2, J4.T, J4.TN, R32.1
/L0: C10.2, C19.1, JP6.2 (B), R1.1, R3.1, R8.1, R17.2, R19.1, R27.1
/R: C6.2, J4.R, J4.RN, R31.1
/R0: C2.2, C3.1, JP6.1 (A), R7.1, R9.1, R14.2, R18.1, R24.1, R36.2
A0: J2.A9 (Pin_a9), U6.48
A1: J2.A10 (Pin_a10), U6.46
A2: J2.A11 (Pin_a11), U6.44
A3: J2.A12 (Pin_a12), U6.42
A4: J2.A24 (Pin_a24), U6.32
A5: J2.A23 (Pin_a23), U6.27
A6: J2.A22 (Pin_a22), U6.33
A7: J2.A21 (Pin_a21), U6.34
A8: J2.B26 (Pin_b26), U2.3 (A0), U5.9 (A0)
A9: J2.A27 (Pin_a27), U5.10 (A1)
A10: J2.B27 (Pin_b27), U5.11 (A2)
A11: J2.A28 (Pin_a28), U5.12 (A3)
A12: J2.A2 (Pin_a2), U5.13 (A4)
A14: J2.A1 (Pin_a1), U6.52
A15: J2.B1 (Pin_b1), U6.51
AY_BC1: U1.29 (BC1), U6.24
AY_BDIR: U1.27 (BDIR), U6.23
AY_CLK: U1.22 (CLOCK), U6.22
CLK8: U6.16 (I/O/GCK2), X1.3 (OUT)
D0: J2.B6 (Pin_b6), U1.37 (DA0), U2.10 (D0), U5.15 (D0), U6.49
D1: J2.B7 (Pin_b7), U1.36 (DA1), U2.11 (D1), U5.16 (D1), U6.60
D2: J2.B8 (Pin_b8), U1.35 (DA2), U2.12 (D2), U5.17 (D2), U6.61
D3: J2.B11 (Pin_b11), U1.34 (DA3), U2.13 (D3), U5.18 (D3), U6.43
D4: J2.B12 (Pin_b12), U1.33 (DA4), U2.14 (D4), U5.19 (D4), U6.40
D5: J2.B10 (Pin_b10), U1.32 (DA5), U2.15 (D5), U5.20 (D5), U6.45
D6: J2.B9 (Pin_b9), U1.31 (DA6), U2.16 (D6), U5.21 (D6), U6.47
D7: J2.B3 (Pin_b3), U1.30 (DA7), U2.17 (D7), U5.22 (D7), U6.50
DAC_L: R17.1, U6.10
DAC_R: R14.1, U6.9
GND: C1.1, C3.2, C4.1, C5.2, C11.2, C12.2, C13.2, C14.2, C15.2, C16.2, C17.2, C19.2, J1.2, J1.10, J2.A6 (Pin_a6), J2.A7 (Pin_a7), J2.A14 (Pin_a14), J3.S, J4.S, R11.2, R12.2, R13.2, R20.2, R21.2, R23.1, R25.2, R28.2, R29.2, R31.2, R32.2, R33.1, R34.2, U1.1 (VSS), U1.24 (~A9~), U2.9 (GND), U3.4 (V-), U4.1 (GND), U5.14 (GND), U6.14 (GND), U6.21 (GND), U6.41 (GND), U6.54 (GND), X1.2 (GND)
unnamed: C2.1, R22.1, R23.2, U3.5 (+)
unnamed: C6.1, RV1.1, U3.7
unnamed: C7.1, C8.2, R26.2, U3.6 (-)
unnamed: C7.2, R25.1
unnamed: C8.1, R26.1, RV1.2, RV1.3
unnamed: C9.1, RV2.3, U3.1
unnamed: C10.1, R30.1, R33.2, U3.3 (+)
unnamed: C18.1, C21.2, U5.2 (CAP1B)
unnamed: C18.2, JP4.1 (A)
unnamed: C20.1, C23.2, R35.2, U3.2 (-)
unnamed: C20.2, R34.1
unnamed: C21.1, JP4.3 (B)
unnamed: C22.1, C24.2, U5.4 (CAP2B)
unnamed: C22.2, JP5.1 (A)
unnamed: C23.1, R35.1, RV2.1, RV2.2
unnamed: C24.1, JP5.3 (B)
unnamed: J3.R, J3.RN, R16.2, R18.2, R21.1
unnamed: J3.T, J3.TN, R15.2, R19.2, R20.1
unnamed: JP1.1 (A), JP2.3 (B), R3.2, R7.2
unnamed: JP1.2 (C), R12.1, U1.3 (B)
unnamed: JP1.3 (B), JP2.1 (A), R9.2
unnamed: JP2.2 (C), R13.1, U1.38 (C)
unnamed: JP4.2 (C), U5.1 (CAP1A)
unnamed: JP5.2 (C), U5.3 (CAP2A)
unnamed: R1.2, R11.1, U1.4 (A)
unnamed: R2.2, R8.2, U2.4 (OutL)
unnamed: R24.2, R27.2, R28.1, U5.27 (AUDIO_OUT)
unnamed: R29.1, U5.26 (EXT_IN)
unnamed: R6.2, R36.1, U2.5 (OutR)
unnamed: R37.2, U2.6 (Iref)
SAA_CLK: U2.8 (CLK), U6.19
SID_CLK: U5.6 (ϕ2), U6.18
SID_CS: U5.8 (~CS), U6.15 (I/O/GCK1)
TCK: J1.1, U6.30 (TCK)
TDI: J1.9, U6.28 (TDI)
TDO: J1.3, U6.53 (TDO)
TMS: J1.5, U6.29 (TMS)
VDDA: C1.2, C4.2, C5.1, JP3.2 (C), R22.2, R30.2, U3.8 (V+), U5.28 (+9V)
~CLKCPU: J2.A8 (Pin_a8), U6.17 (I/O/GCK3), U6.36
~IORQ: J2.B17 (Pin_b17), U6.39
~IORQGE: J2.A13 (Pin_a13), U6.35
~M1: J2.B24 (Pin_b24), U6.31
~RST: J2.A20 (Pin_a20), U1.23 (~RESET~), U5.5 (~RES), U6.64 (I/O/GSR)
~SAA_CS: U2.2 (~CS), U6.20
~WR: J2.B19 (Pin_b19), U2.1 (~WR), U5.7 (R/~W), U6.38

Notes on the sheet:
470p for 6581 22n for 8580
+12V for 6581 +9V for 8580
1-2 ABC 2-3 ACB

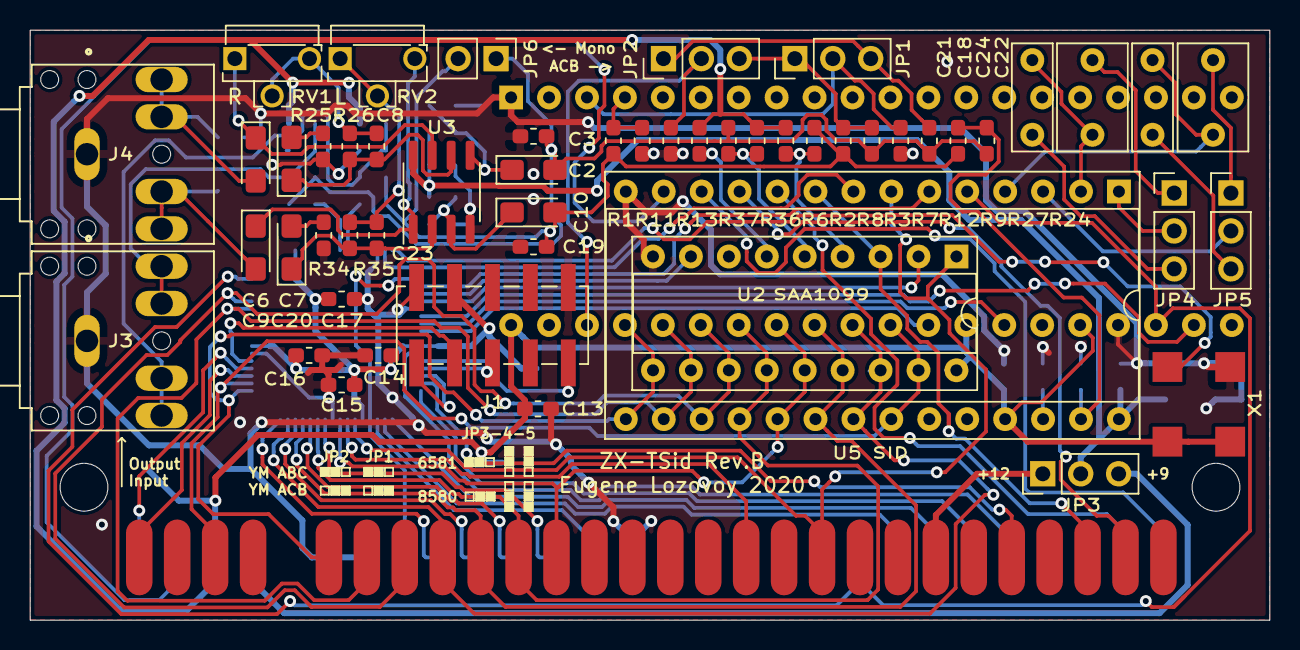
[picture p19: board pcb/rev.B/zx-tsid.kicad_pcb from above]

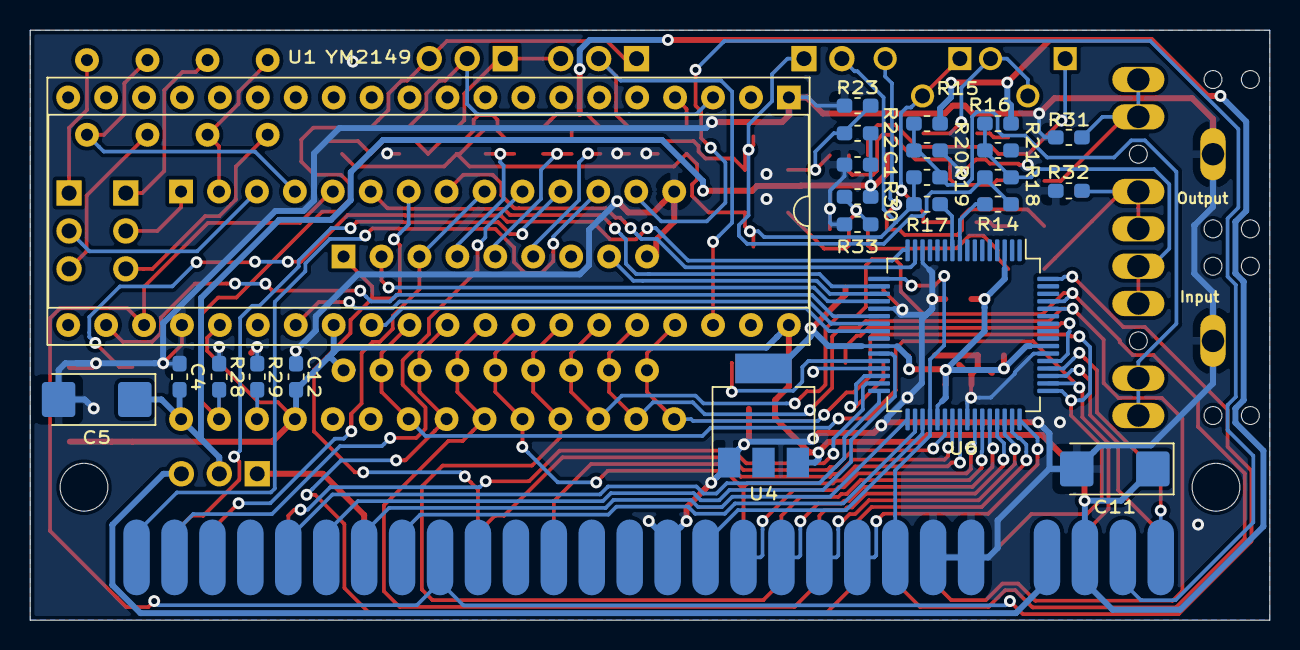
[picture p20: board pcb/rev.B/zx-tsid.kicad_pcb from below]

Board: 2 copper layers, 83.0 x 39.5 mm, 79 parts (24 on the bottom side), 83 nets.

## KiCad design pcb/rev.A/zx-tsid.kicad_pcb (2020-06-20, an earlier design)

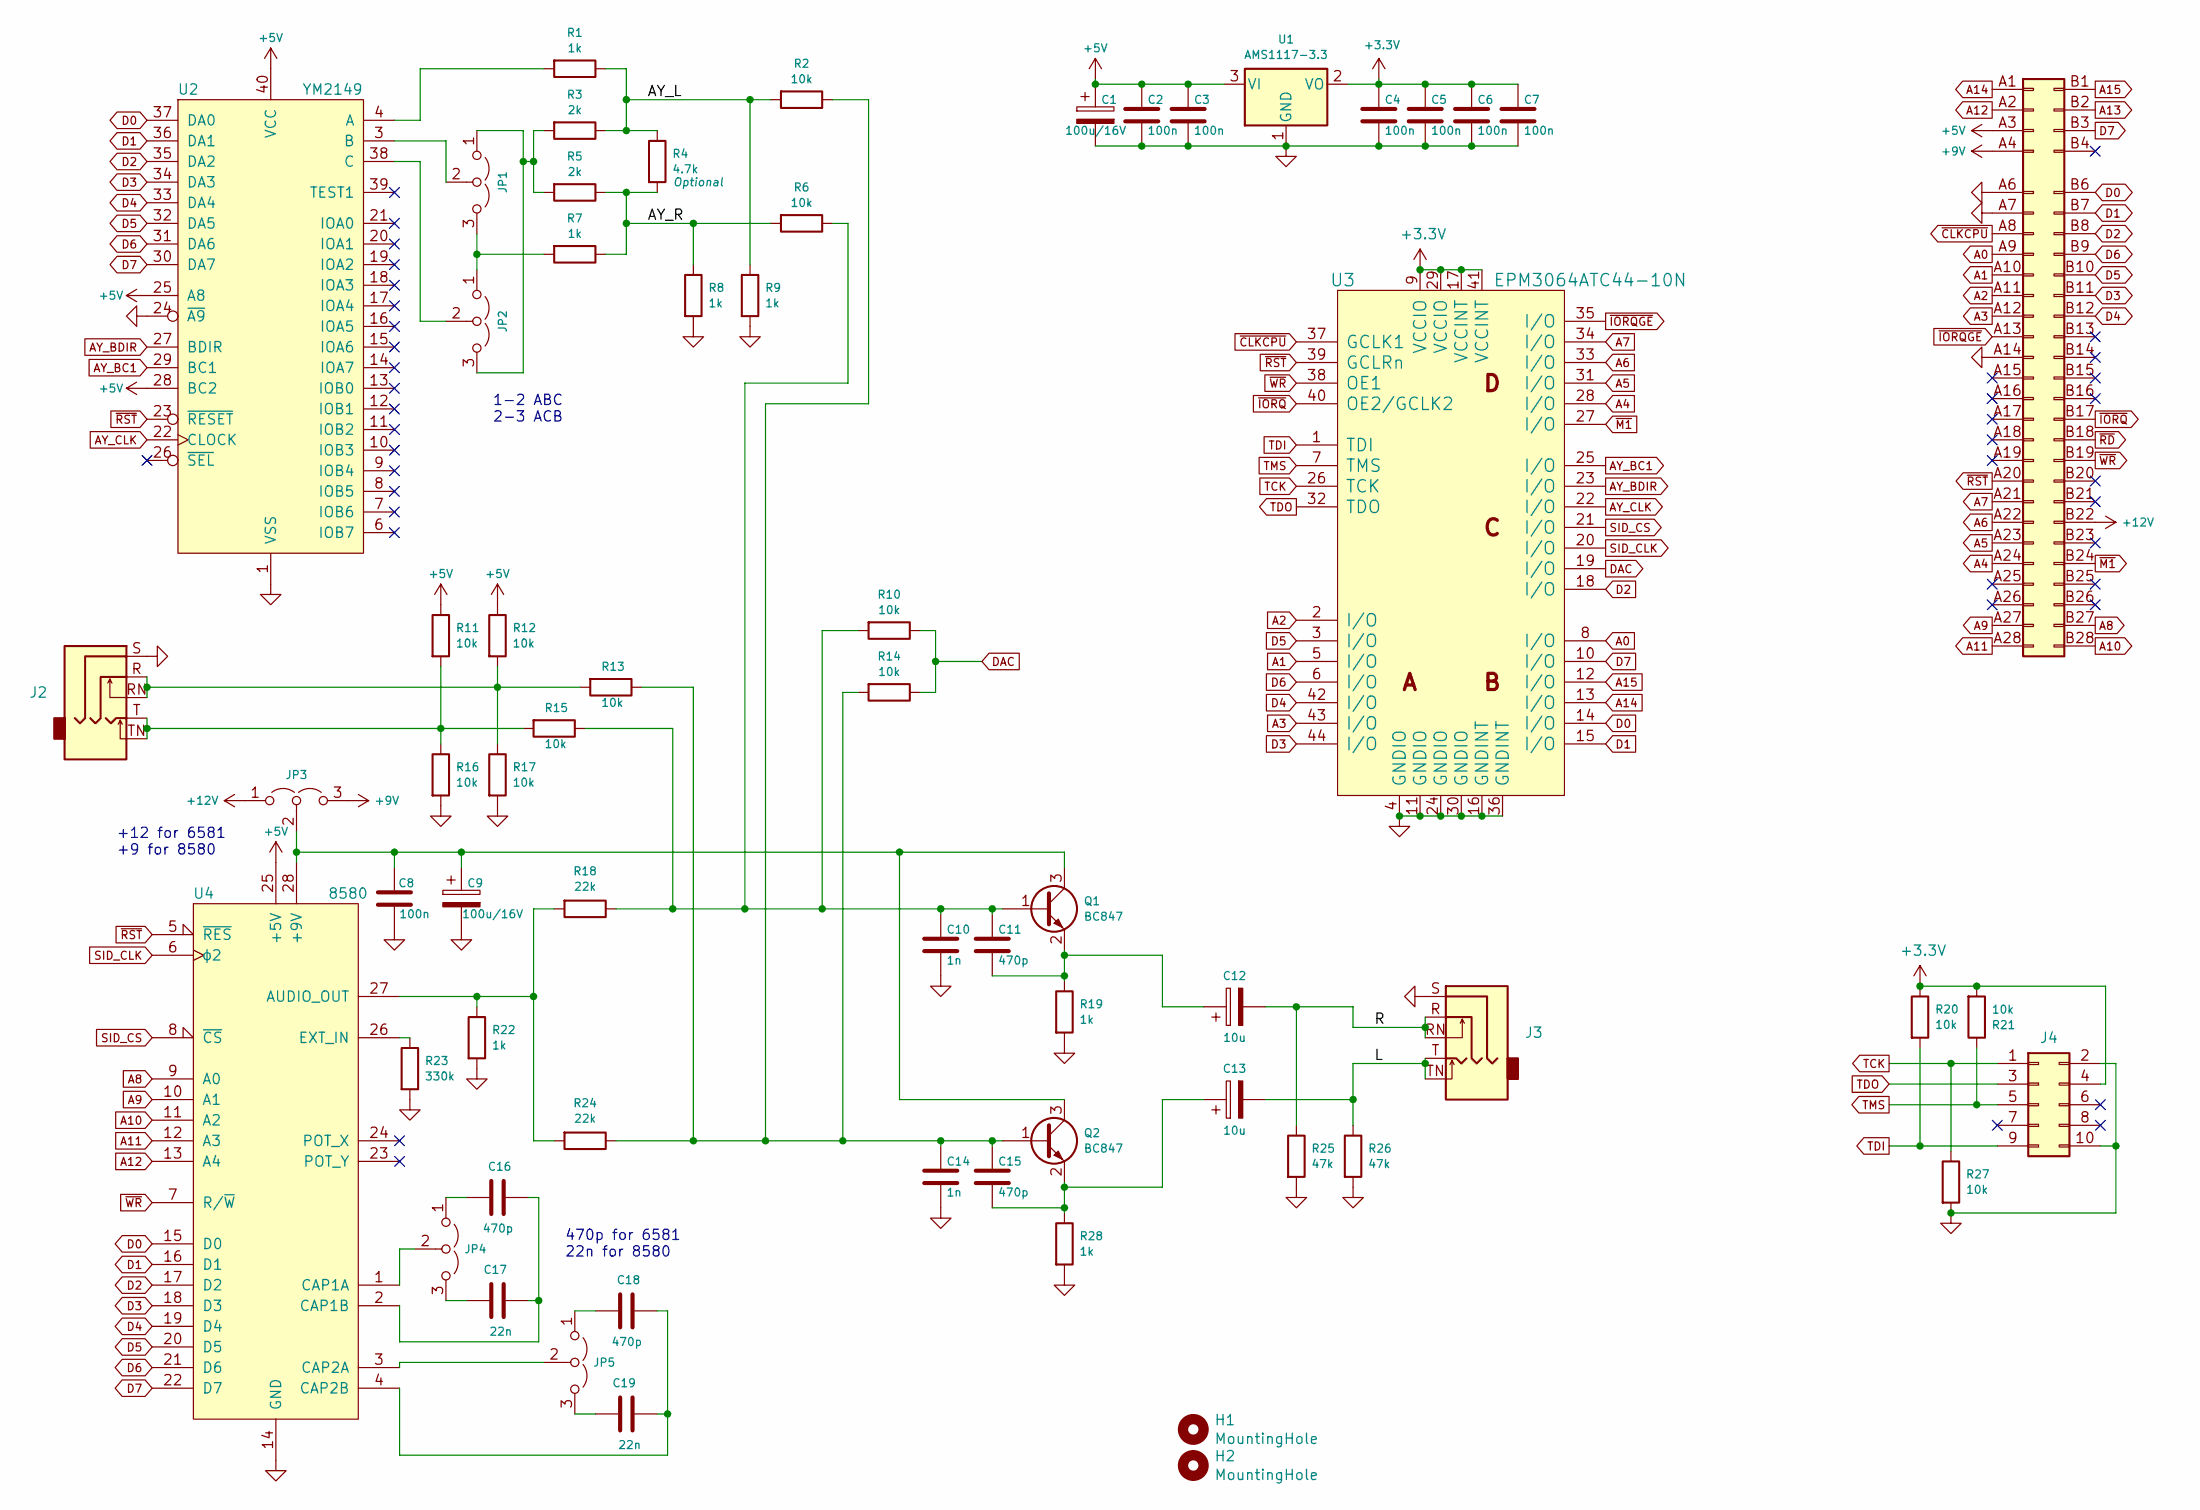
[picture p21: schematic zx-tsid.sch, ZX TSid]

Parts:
C1, C9: 100u/16V; CP_EIA-6032-15_Kemet-U_Pad2.25x2.35mm_HandSolder
C2, C3, C4, C5, C6, C7, C8: 100n; C_0603_1608Metric_Pad1.05x0.95mm_HandSolder
C10, C14: 1n; C_0603_1608Metric_Pad1.05x0.95mm_HandSolder
C11, C15: 470p; C_0603_1608Metric_Pad1.05x0.95mm_HandSolder
C12, C13: 10u; CP_Elec_6.3x5.4
C16, C18: 470p; C_Rect_L7.0mm_W4.5mm_P5.00mm
C17, C19: 22n; C_Rect_L7.0mm_W2.5mm_P5.00mm
H1, H2: MountingHole; MountingHole_3.2mm_M3
J1: zx_edge; ZX_CONN
J2, J3: PJ307; SWITCHCRAFT_35RAPC4BHN2
J4: Conn_02x05_Odd_Even; PinHeader_2x05_P2.54mm_Vertical_SMD
JP1, JP2, JP3, JP4, JP5: Jumper_3_Open; PinHeader_1x03_P2.54mm_Vertical
Q1, Q2: BC847; SOT-23_Handsoldering
R1, R7, R8, R9, R19, R22, R28: 1k; R_0603_1608Metric_Pad1.05x0.95mm_HandSolder
R2, R6, R10, R11, R12, R13, R14, R15, R16, R17, R20, R21, R27: 10k; R_0603_1608Metric_Pad1.05x0.95mm_HandSolder
R3, R5: 2k; R_0603_1608Metric_Pad1.05x0.95mm_HandSolder
R4: 4.7k; R_0603_1608Metric_Pad1.05x0.95mm_HandSolder
R18, R24: 22k; R_0603_1608Metric_Pad1.05x0.95mm_HandSolder
R23: 330k; R_0603_1608Metric_Pad1.05x0.95mm_HandSolder
R25, R26: 47k; R_0603_1608Metric_Pad1.05x0.95mm_HandSolder
U1: AMS1117-3.3; SOT-223-3_TabPin2
U2: YM2149; DIP-40_W15.24mm_Socket
U3: EPM3064ATC44-10N; QFP80P1200X1200X120-44N
U4: 8580; DIP-28_W15.24mm_Socket

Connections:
+3V3: C4.1, C5.1, C6.1, C7.1, J4.4, R20.1, R21.2, U1.2 (VO), U3.9 (VCCIO), U3.17 (VCCINT), U3.29 (VCCIO), U3.41 (VCCINT)
+5V: C1.1, C2.1, C3.1, J1.A3 (Pin_a3), R11.1, R12.1, U1.3 (VI), U2.25 (A8), U2.28 (BC2), U2.40 (VCC), U4.25 (+5V)
+9V: J1.A4 (Pin_a4), JP3.3 (B)
+12V: J1.B22 (Pin_b22), JP3.1 (A)
/AY_L: R1.1, R2.2, R3.1, R4.1, R9.1
/AY_R: R4.2, R5.1, R6.2, R7.1, R8.1
/L: C13.2, J3.T, J3.TN, R26.1
/R: C12.2, J3.R, J3.RN, R25.1
A0: J1.A9 (Pin_a9), U3.8 (I/O)
A1: J1.A10 (Pin_a10), U3.5 (I/O)
A2: J1.A11 (Pin_a11), U3.2 (I/O)
A3: J1.A12 (Pin_a12), U3.43 (I/O)
A4: J1.A24 (Pin_a24), U3.28 (I/O)
A5: J1.A23 (Pin_a23), U3.31 (I/O)
A6: J1.A22 (Pin_a22), U3.33 (I/O)
A7: J1.A21 (Pin_a21), U3.34 (I/O)
A8: J1.B27 (Pin_b27), U4.9 (A0)
A9: J1.A27 (Pin_a27), U4.10 (A1)
A10: J1.B28 (Pin_b28), U4.11 (A2)
A11: J1.A28 (Pin_a28), U4.12 (A3)
A12: J1.A2 (Pin_a2), U4.13 (A4)
A14: J1.A1 (Pin_a1), U3.13 (I/O)
A15: J1.B1 (Pin_b1), U3.12 (I/O)
AY_BC1: U2.29 (BC1), U3.25 (I/O)
AY_BDIR: U2.27 (BDIR), U3.23 (I/O)
AY_CLK: U2.22 (CLOCK), U3.22 (I/O)
D0: J1.B6 (Pin_b6), U2.37 (DA0), U3.14 (I/O), U4.15 (D0)
D1: J1.B7 (Pin_b7), U2.36 (DA1), U3.15 (I/O), U4.16 (D1)
D2: J1.B8 (Pin_b8), U2.35 (DA2), U3.18 (I/O), U4.17 (D2)
D3: J1.B11 (Pin_b11), U2.34 (DA3), U3.44 (I/O), U4.18 (D3)
D4: J1.B12 (Pin_b12), U2.33 (DA4), U3.42 (I/O), U4.19 (D4)
D5: J1.B10 (Pin_b10), U2.32 (DA5), U3.3 (I/O), U4.20 (D5)
D6: J1.B9 (Pin_b9), U2.31 (DA6), U3.6 (I/O), U4.21 (D6)
D7: J1.B3 (Pin_b3), U2.30 (DA7), U3.10 (I/O), U4.22 (D7)
DAC: R10.1, R14.1, U3.19 (I/O)
GND: C1.2, C2.2, C3.2, C4.2, C5.2, C6.2, C7.2, C8.1, C9.2, C10.2, C14.2, J1.A6 (Pin_a6), J1.A7 (Pin_a7), J1.A14 (Pin_a14), J2.S, J3.S, J4.2, J4.10, R8.2, R9.2, R16.2, R17.2, R19.2, R22.2, R23.2, R25.2, R26.2, R27.2, R28.2, U1.1 (GND), U2.1 (VSS), U2.24 (~A9~), U3.4 (GNDIO), U3.11 (GNDIO), U3.16 (GNDINT), U3.24 (GNDIO), U3.30 (GNDIO), U3.36 (GNDINT), U4.14 (GND)
unnamed: C8.2, C9.1, JP3.2 (C), Q1.3 (C), Q2.3 (C), U4.28 (+9V)
unnamed: C10.1, C11.1, Q1.1 (B), R6.1, R10.2, R15.1, R18.1
unnamed: C11.2, C12.1, Q1.2 (E), R19.1
unnamed: C13.1, C15.2, Q2.2 (E), R28.1
unnamed: C14.1, C15.1, Q2.1 (B), R2.1, R13.1, R14.2, R24.1
unnamed: C16.1, C17.2, U4.2 (CAP1B)
unnamed: C16.2, JP4.1 (A)
unnamed: C17.1, JP4.3 (B)
unnamed: C18.1, C19.2, U4.4 (CAP2B)
unnamed: C18.2, JP5.1 (A)
unnamed: C19.1, JP5.3 (B)
unnamed: J2.R, J2.RN, R12.2, R13.2, R17.1
unnamed: J2.T, J2.TN, R11.2, R15.2, R16.1
unnamed: JP1.1 (A), JP2.3 (B), R3.2, R5.2
unnamed: JP1.2 (C), U2.3 (B)
unnamed: JP1.3 (B), JP2.1 (A), R7.2
unnamed: JP2.2 (C), U2.38 (C)
unnamed: JP4.2 (C), U4.1 (CAP1A)
unnamed: JP5.2 (C), U4.3 (CAP2A)
unnamed: R1.2, U2.4 (A)
unnamed: R18.2, R22.1, R24.2, U4.27 (AUDIO_OUT)
unnamed: R23.1, U4.26 (EXT_IN)
SID_CLK: U3.20 (I/O), U4.6 (ϕ2)
SID_CS: U3.21 (I/O), U4.8 (~CS)
TCK: J4.1, R27.1, U3.26 (TCK)
TDI: J4.9, R20.2, U3.1 (TDI)
TDO: J4.3, U3.32 (TDO)
TMS: J4.5, R21.1, U3.7 (TMS)
~CLKCPU: J1.A8 (Pin_a8), U3.37 (GCLK1)
~IORQ: J1.B17 (Pin_b17), U3.40 (OE2/GCLK2)
~IORQGE: J1.A13 (Pin_a13), U3.35 (I/O)
~M1: J1.B24 (Pin_b24), U3.27 (I/O)
~RST: J1.A20 (Pin_a20), U2.23 (~RESET~), U3.39 (GCLRn), U4.5 (~RES)
~WR: J1.B19 (Pin_b19), U3.38 (OE1), U4.7 (R/~W)

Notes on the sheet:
470p for 6581 22n for 8580
+12 for 6581 +9 for 8580
1-2 ABC 2-3 ACB

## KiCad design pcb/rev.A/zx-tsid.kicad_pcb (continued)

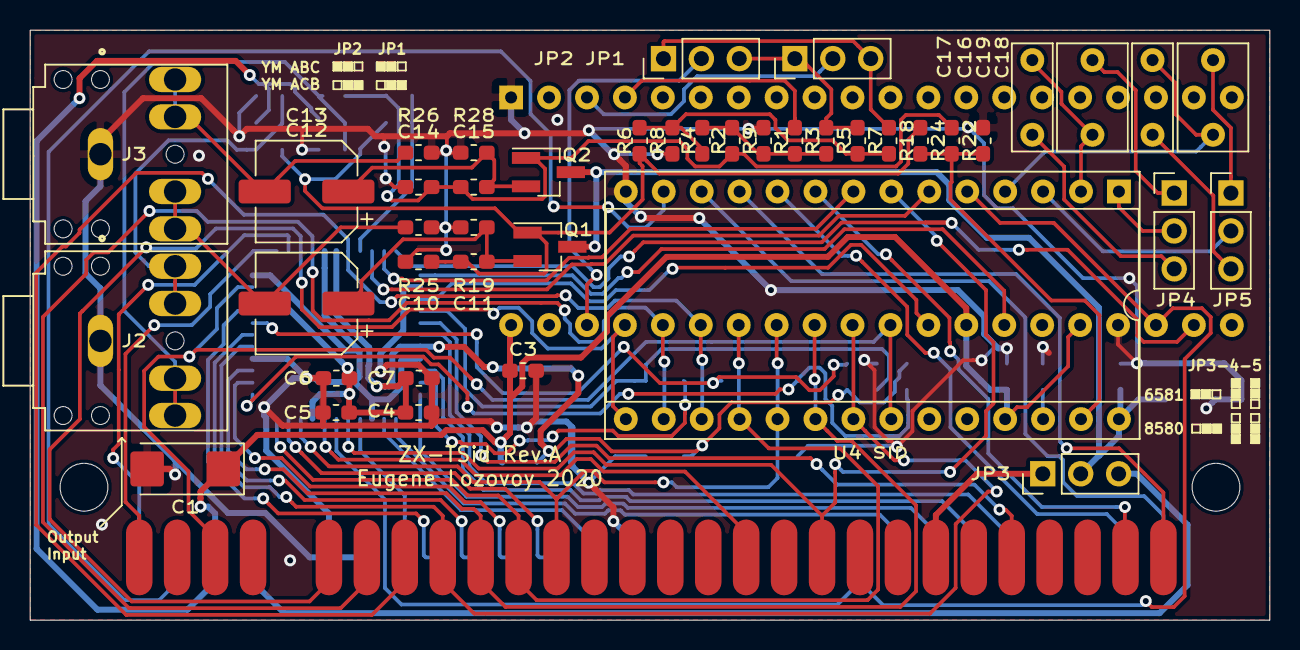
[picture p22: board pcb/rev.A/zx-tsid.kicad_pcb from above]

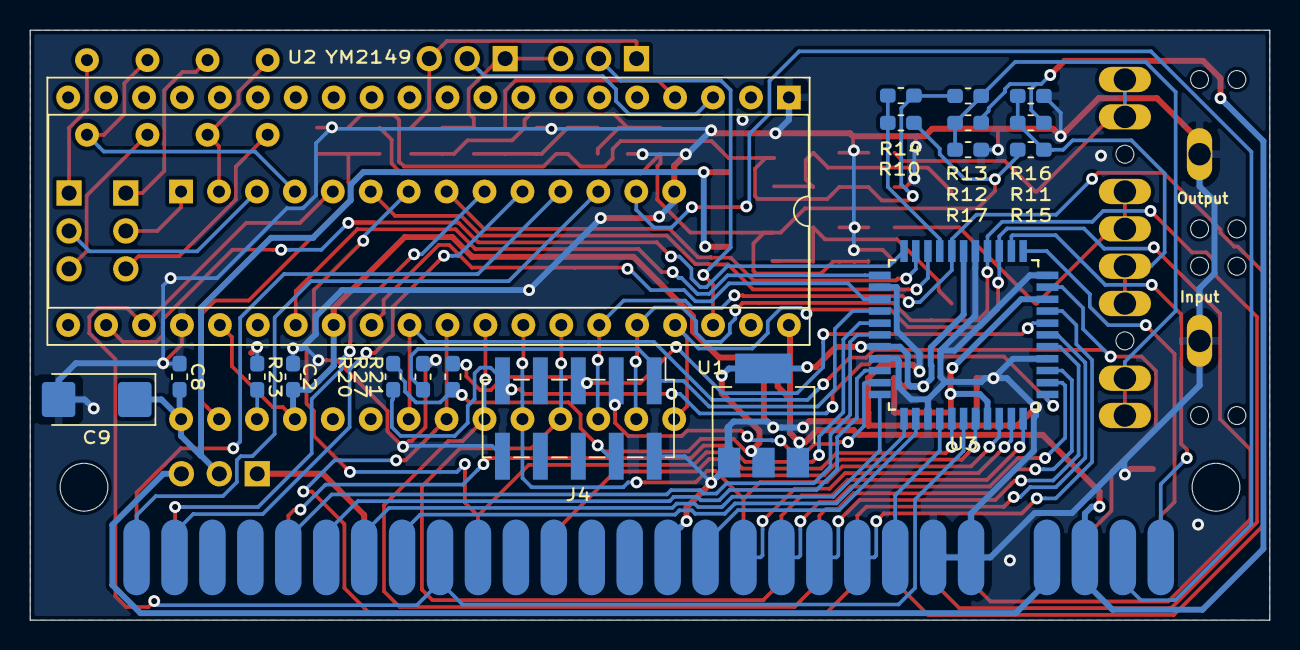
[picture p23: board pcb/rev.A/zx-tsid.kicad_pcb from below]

Board: 2 copper layers, 83.0 x 39.5 mm, 64 parts (19 on the bottom side), 70 nets.

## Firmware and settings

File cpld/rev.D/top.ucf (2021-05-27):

#PACE: Start of Constraints generated by PACE
#PACE: Start of PACE I/O Pin Assignments
NET "a<0>"  LOC = "p40"  ;
NET "a<10>"  LOC = "p61"  ;
NET "a<11>"  LOC = "p60"  ;
NET "a<12>"  LOC = "p33"  ;
NET "a<14>"  LOC = "p31"  ;
NET "a<15>"  LOC = "p32"  ;
NET "a<1>"  LOC = "p42"  ;
NET "a<2>"  LOC = "p43"  ;
NET "a<3>"  LOC = "p51"  ;
NET "a<4>"  LOC = "p39"  ;
NET "a<5>"  LOC = "p35"  ;
NET "a<6>"  LOC = "p36"  ;
NET "a<7>"  LOC = "p34"  ;
NET "a<8>"  LOC = "p57"  ;
NET "a<9>"  LOC = "p59"  ;
NET "cfg"  LOC = "p27"  ;
NET "clk32"  LOC = "p17"  ;
NET "clkcpu"  LOC = "p15"  ;
NET "d<0>"  LOC = "p44"  ;
NET "d<1>"  LOC = "p45"  ;
NET "d<2>"  LOC = "p46"  ;
NET "d<3>"  LOC = "p49"  ;
NET "d<4>"  LOC = "p58"  ;
NET "d<5>"  LOC = "p48"  ;
NET "d<6>"  LOC = "p47"  ;
NET "d<7>"  LOC = "p38"  ;
NET "n_iorq"  LOC = "p50"  ;
NET "n_iorqge"  LOC = "p52"  ;
NET "n_rd"  LOC = "p63"  ;
NET "n_wait" LOC = "p56" ;
NET "n_wr"  LOC = "p62"  ;
NET "rst_n"  LOC = "p64"  ;
NET "sid_a<0>"  LOC = "p8"  ;
NET "sid_a<1>"  LOC = "p7"  ;
NET "sid_a<2>"  LOC = "p4"  ;
NET "sid_a<3>"  LOC = "p5"  ;
NET "sid_a<4>"  LOC = "p2"  ;
NET "sid_clk"  LOC = "p1"  ;
NET "sid_cs"  LOC = "p6"  ;
NET "sid_d<0>"  LOC = "p16"  ;
NET "sid_d<1>"  LOC = "p9"  ;
NET "sid_d<2>"  LOC = "p12"  ;
NET "sid_d<3>"  LOC = "p19"  ;
NET "sid_d<4>"  LOC = "p18"  ;
NET "sid_d<5>"  LOC = "p20"  ;
NET "sid_d<6>"  LOC = "p10"  ;
NET "sid_d<7>"  LOC = "p11"  ;
NET "sid_rst"  LOC = "p23"  ;
NET "sid_wr"  LOC = "p13"  ;

#PACE: Start of PACE Area Constraints
#PACE: Start of PACE Prohibit Constraints
#PACE: End of Constraints generated by PACE
#Created by Constraints Editor (xc9572xl-vq64-10) - 2020/12/09
NET "clk32" TNM_NET = clk32;
TIMESPEC TS_clk32 = PERIOD "clk32" 32 MHz HIGH 50%;
NET "clkcpu" TNM_NET = clkcpu;
TIMESPEC TS_clkcpu = PERIOD "clkcpu" 7 MHz HIGH 50%;

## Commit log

2020-06-20 add delivered files (gerbers, firmware binary, etc) for rev.A
    [zx-tsid.kicad_pcb, zx-tsid.sch]
2020-10-20 pcb: add errata for rev.A
2021-03-16 add pcb rev.B
    [zx-tsid.kicad_pcb, zx-tsid.sch]
2021-03-16 add pcb rev.C
    [zx-tsid.kicad_pcb, zx-tsid.sch]
2021-03-16 add pcb rev.D
    [zx-tsid.kicad_pcb, zx-tsid.sch]
2021-03-16 move cpld firmware for rev.A pcb to dedicated directory
2021-03-16 add cpld firmware for pcb rev.C
2021-04-26 fix compatibility with real SID chip (but still isn't tested)
    [top.ucf]
2021-04-26 add cpld firmware for rev.D pcb
2021-05-27 fix pinout for cpld rev.D firmware
    [top.ucf]
2023-09-19 update readme and pcb photo
